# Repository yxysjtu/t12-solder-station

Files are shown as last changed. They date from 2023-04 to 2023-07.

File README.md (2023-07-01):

# t12-solder-station

bare-bone version
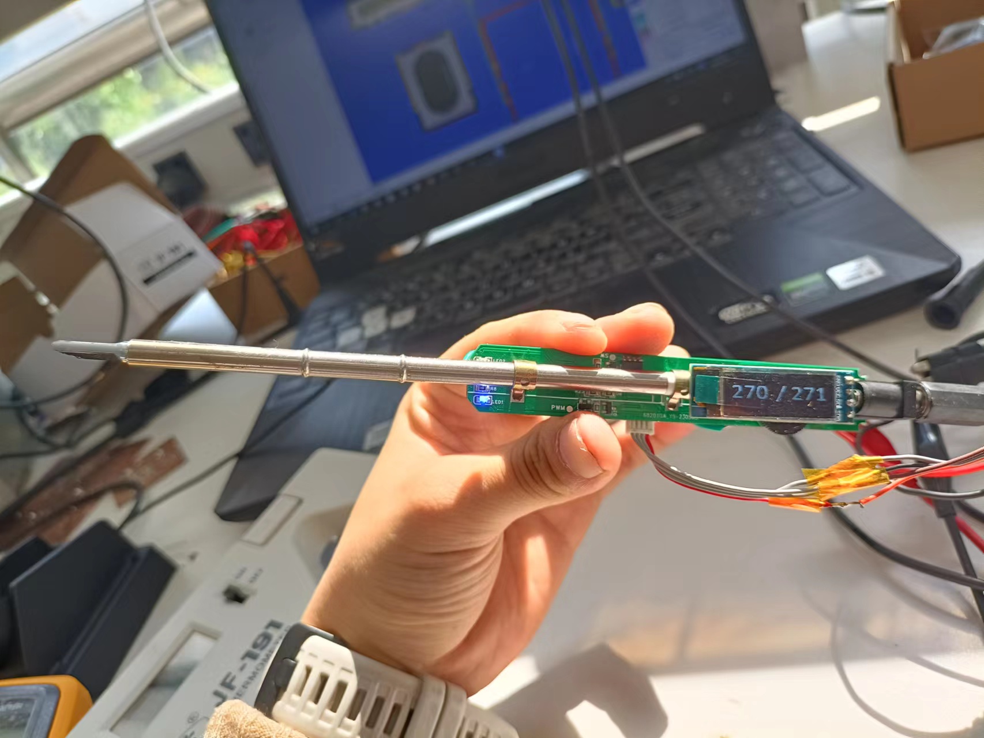
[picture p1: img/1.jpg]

with 3D-printed nylon shell
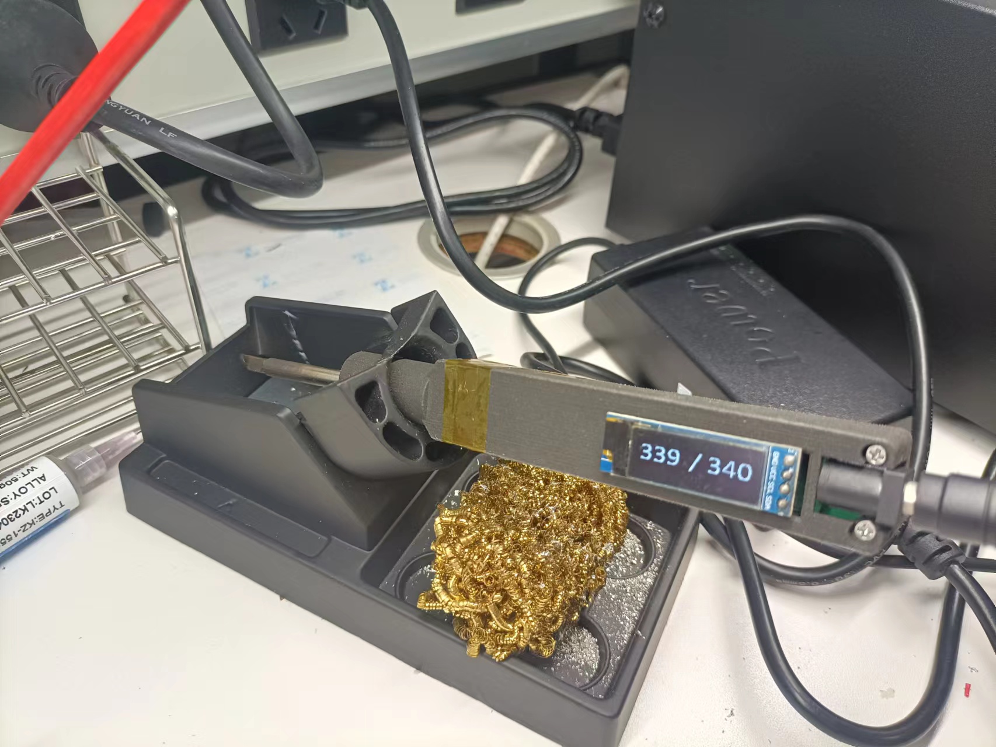
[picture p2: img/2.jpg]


## Feature
* regulate the temperature on the tip of soldering iron according to the set temperature (200 - 400 degree)
* using a 0.92 inch OLED to display current temperature and set temperature
* set the temperature using a rotary potentiometer
* auto sleep and wake function according to sensed vibration

## Working principle
1. using PWM wave to control power output to the iron
2. T12 iron tip is made of a type of thermocouple which can be seen as a 8 ohm resistor in series with a temperature-controlled-voltage-source that output voltage in proportion to temperature(in mV), so I use OPA376 opamp to amplify the voltage between two terminals of the iron(the voltage should be measured between the off stage, because when the iron is on, the voltage across it is 24V(so I use a 3.3V zener diode to clamp the voltage feeding into the input port of the opamp in case of destroying it))
3. the amplified voltage then goes to ADC of the MCU, forming a negative feedback
4. using PID controller to control PWM duty cycle, aiming to regulate temperature fast and accurately

## Schematic
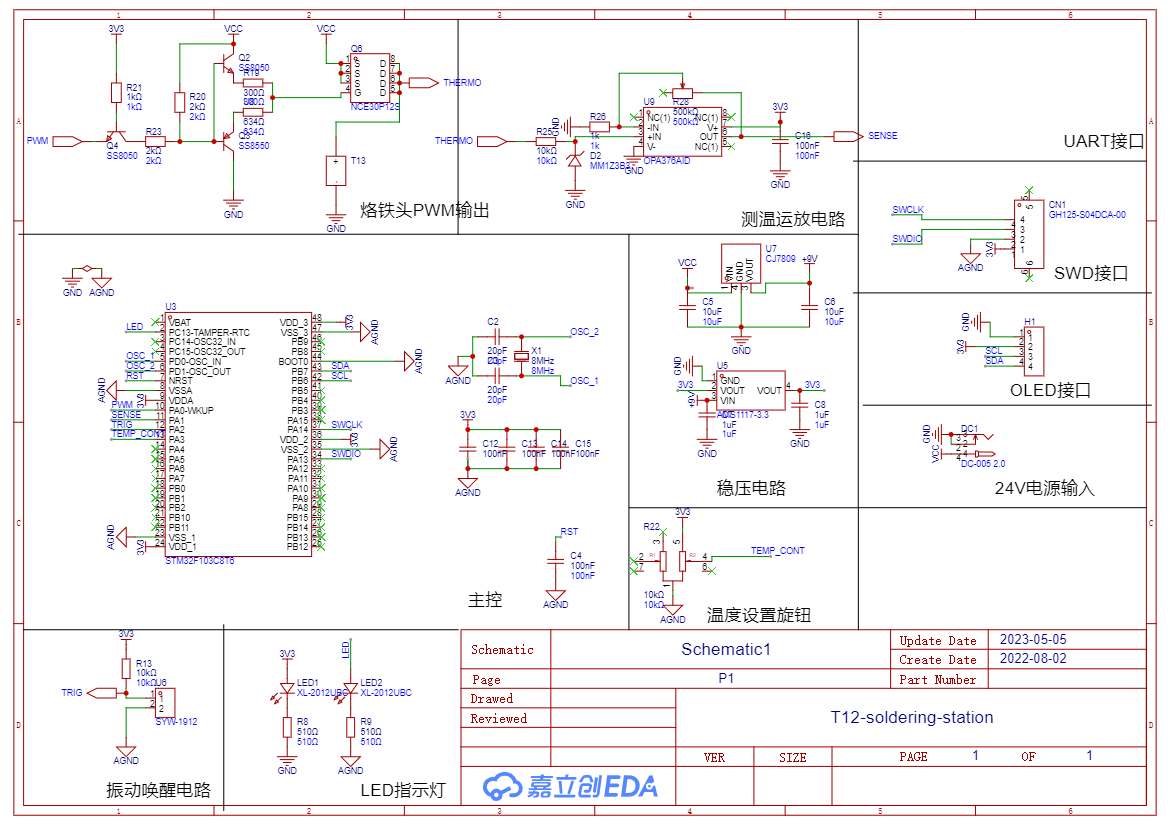
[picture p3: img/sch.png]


## PCB
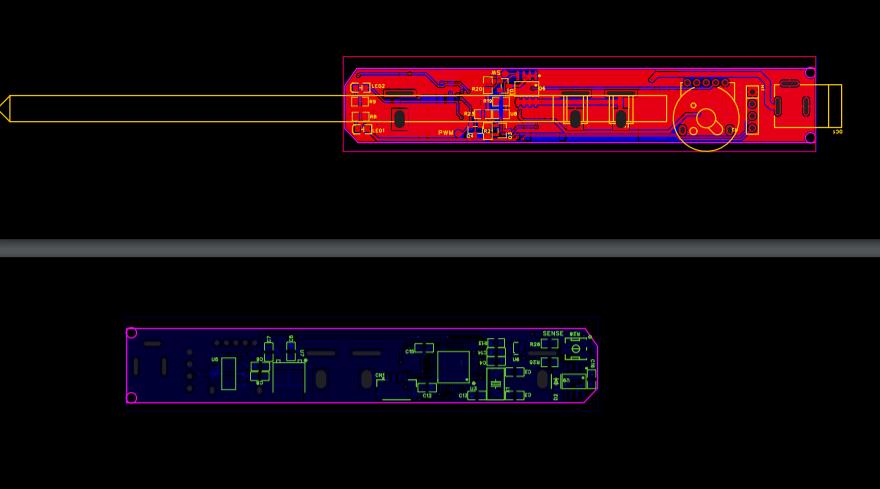
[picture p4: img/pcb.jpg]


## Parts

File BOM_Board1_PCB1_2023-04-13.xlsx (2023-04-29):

No. | Quantity | Comment | Designator | Footprint | Value | Manufacturer Part | Manufacturer | Supplier Part | Supplier
1 | 5 | 100nF | C1,C12,C13,C14,C15 | C0805 | 100nF
2 | 2 | 20pF | C2,C3 | C0805 | 20pF | 0805CG200J500NT | FH(风华) | C94472 | LCSC
3 | 2 | 100nF | C4,C11 | C0805 | 100nF | NL0805B104M500CPBN | HUI JU(汇聚) | C720961 | LCSC
4 | 2 | 10uF | C5,C6 | C0805 | 10uF | GRM21BR61H106KE43L | muRata(村田) | C440198 | LCSC
5 | 2 | 1uF | C7,C8 | C0805 | 1uF | CL21B105KBFNNNE | SAMSUNG(三星) | C28323 | LCSC
6 | 1 | GH125-S04DCA-00 | CN1 | CONN-SMD_4P-P1.27_GH125-S04DCA-00 |  | GH125-S04DCA-00 | JS(钜硕电子) | C2886767 | LCSC
7 | 1 | 70ADJ-2-ML1 | CN3 | CONN-SMD_70ADJ-2-ML1 |  | 70ADJ-2-ML1 | BOURNS | C194556 | LCSC
8 | 1 | MM1Z3B3 | D1 | SOD-123_L2.8-W1.8-LS3.7-FD |  | MM1Z3B3 | ST(先科) | C108453 | LCSC
9 | 1 | DC-005 2.0 | DC1 | DC-IN-TH_DC-5520-1 |  | DC-005 2.0 | BOOMELE(博穆精密) | C16214 | LCSC
10 | 1 |  | H1 | HDR-TH_4P-P2.54-V-M |  |  |  | C492403
11 | 2 | XL-2012UBC | HEAT,POWER | LED0805-RD |  | XL-2012UBC | XINGLIGHT(成兴光) | C965817 | LCSC
12 | 2 | SS8050 | Q2,Q4 | SOT-23-3_L2.9-W1.3-P1.90-LS2.4-BR |  | SS8050 | CJ（江苏长电/长晶） | C2150 | LCSC
13 | 1 | SS8550 | Q3 | SOT-23-3_L2.9-W1.6-P1.90-LS2.8-BR |  | SS8550 | CJ（江苏长电/长晶） | C105430 | LCSC
14 | 1 | AP4410 | Q5 | SOP-8_L4.9-W3.8-P1.27-LS6.0-BL |  | AP4410 | ALLPOWER(铨力) | C2837277 | LCSC
15 | 1 | 5kΩ | R2 | RES-ADJ-SMD_3P-L4.5-W4.5-P2.35-BR | 5kΩ | 3314G-1-502E | BOURNS | C719180 | LCSC
16 | 3 | 10kΩ | R3,R7,R13 | R0805 | 10kΩ | 0805W8F1002T5E | UNI-ROYAL(厚声) | C17414 | LCSC
17 | 1 | 1MΩ | R6 | R0805 | 1MΩ | 0805W8F1004T5E | UNI-ROYAL(厚声) | C17514 | LCSC
18 | 2 | 510Ω | R8,R9 | R0805 | 510Ω | 0805W8F5100T5E | UNI-ROYAL(厚声) | C17734 | LCSC
19 | 2 | 120Ω | R10,R11 | R0805 | 120Ω | 0805W8F1200T5E | UNI-ROYAL(厚声) | C17437 | LCSC
20 | 3 | 1kΩ | R14,R15,R21 | R0805 | 1kΩ | ERJPB6B1001V | PANASONIC(松下) | C413712 | LCSC
21 | 1 | 100Ω | R16 | R0805 | 100Ω | ERJP06J101V | PANASONIC(松下) | C417003 | LCSC
22 | 1 | 300Ω | R19 | R0805 | 300Ω | RK73B2ATTD301J | KOA | C316763 | LCSC
23 | 1 | 2kΩ | R20 | R0805 | 2kΩ | ERJPB6B2001V | PANASONIC(松下) | C413705 | LCSC
24 | 1 | 10kΩ | R22 | RES-TH_RK10J12E002L | 10kΩ | RK10J12E002L | ALPSALPINE(阿尔卑斯阿尔派) | C231765 | LCSC
25 | 1 | INA826AIDR | U2 | SOIC-8_L4.9-W3.9-P1.27-LS6.0-BL |  | INA826AIDR | TI(德州仪器) | C38433 | LCSC
26 | 1 | STM32F103C8T6 | U3 | LQFP-48_L7.0-W7.0-P0.50-LS9.0-BL |  | STM32F103C8T6 | ST(意法半导体) | C8734 | LCSC
27 | 1 | AMS1117-3.3 | U5 | SOT-223-3_L6.5-W3.4-P2.30-LS7.0-BR |  | AMS1117-3.3 | AMS | C6186 | LCSC
28 | 1 | SYW-1912 | U6 | SENSOR-SMD_SYW-1912 |  | SYW-1912 | saiya(赛亚) | C3040975 | LCSC
29 | 1 | CJ7809 | U7 | TO-252-2_L6.5-W6.1-P4.58-LS10.0-TL |  | CJ7809 | CJ（江苏长电/长晶） | C177737 | LCSC
30 | 1 | 634Ω | U8 | R0805 | 634Ω | HPCR0805F634RK9 | RESI(开步睿思） | F | LCSC
31 | 1 | 8MHz | X1 | CRYSTAL-SMD_L5.0-W3.2 | 8MHz | X50328MSB2GI | YXC(扬兴晶振) | C115962 | LCSC

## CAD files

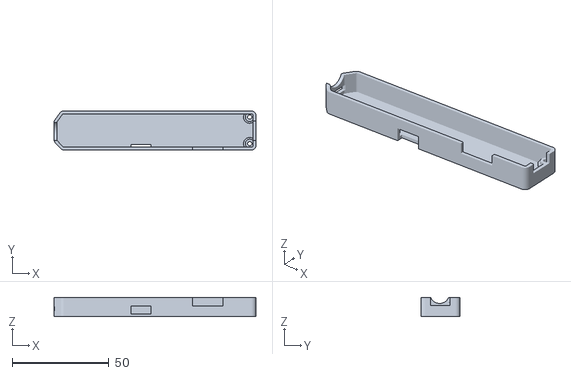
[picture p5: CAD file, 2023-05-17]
3DShell_PCB3/3DShell_3DShell_PCB1_B.stl
104.2 x 20.1 x 10.0

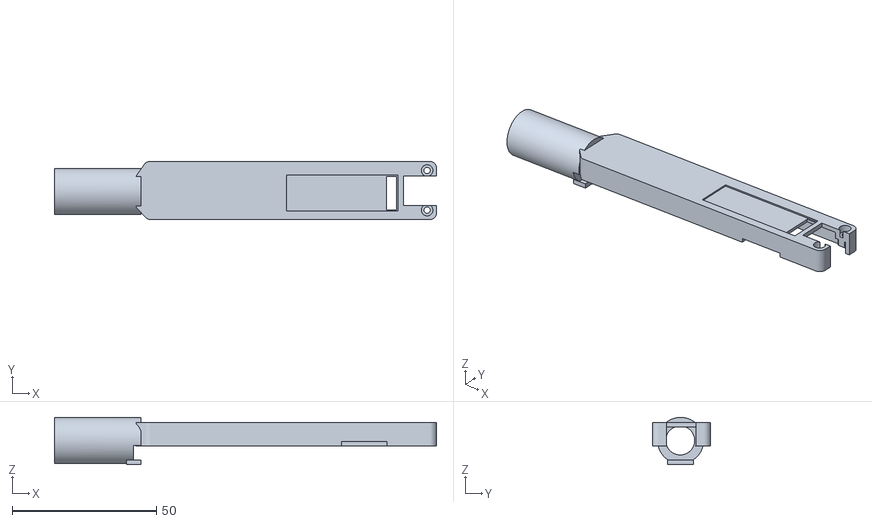
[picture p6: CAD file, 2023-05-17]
3DShell_PCB3/3DShell_3DShell_PCB1_T.stl
132.2 x 20.1 x 16.4

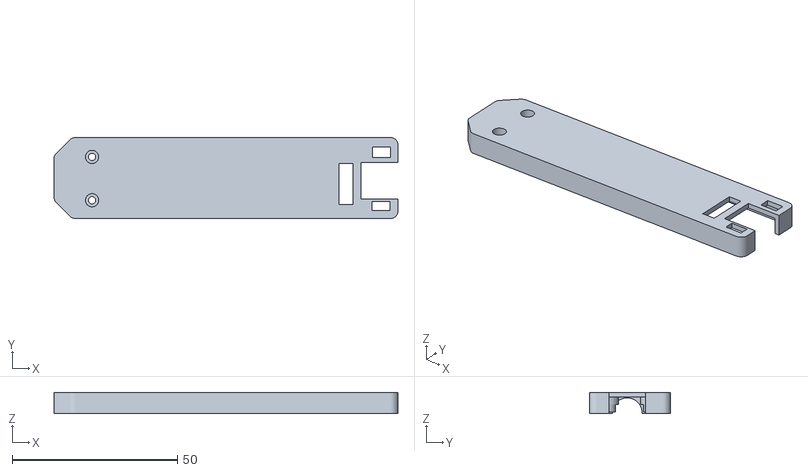
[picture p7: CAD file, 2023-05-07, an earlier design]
3DShell_PCB1/3DShell_3DShell_PCB1_T.stl
104.1 x 24.5 x 6.50

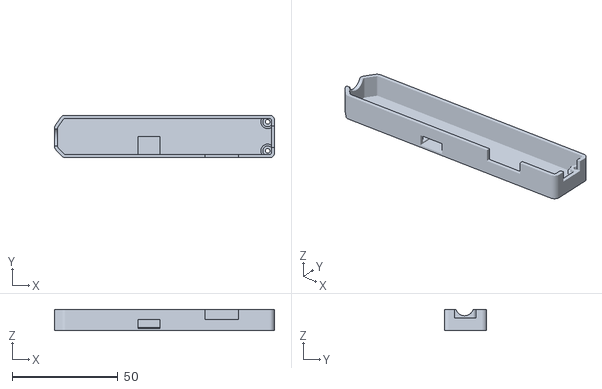
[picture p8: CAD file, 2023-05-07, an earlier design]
3DShell_PCB2/3DShell_3DShell_PCB1_B.stl
104.2 x 20.1 x 10.0

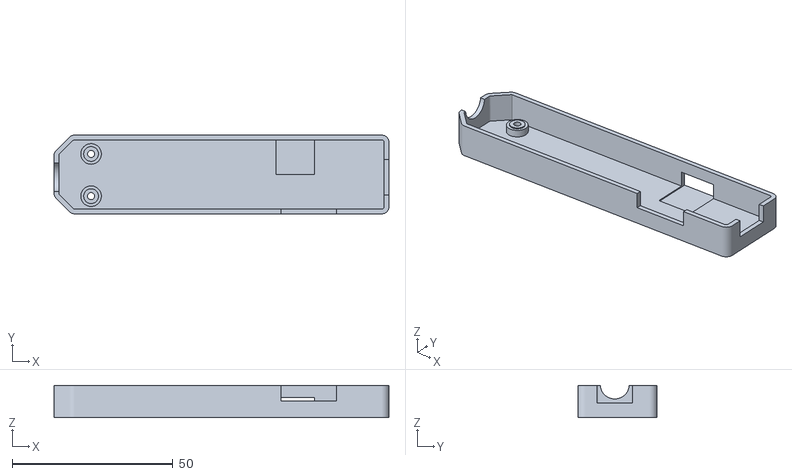
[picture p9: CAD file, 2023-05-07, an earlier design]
3DShell_PCB1/3DShell_3DShell_PCB1_B.stl
104.1 x 24.5 x 10.0

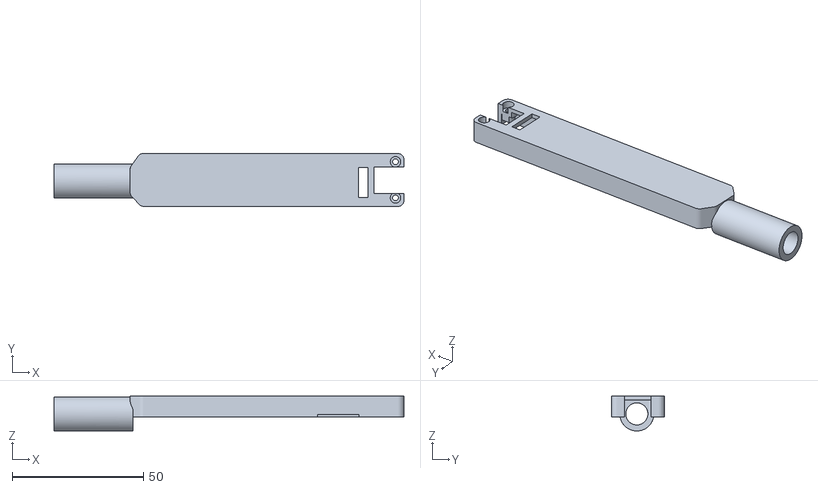
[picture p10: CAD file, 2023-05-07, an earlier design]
3DShell_PCB2/3DShell_3DShell_PCB1_T.stl
133.1 x 20.1 x 13.3

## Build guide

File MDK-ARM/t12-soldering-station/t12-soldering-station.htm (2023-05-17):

# Static Call Graph for image t12-soldering-station\t12-soldering-station.axf

#<CALLGRAPH># ARM Linker, 5060750: Last Updated: Thu May 11 15:21:41 2023

### Maximum Stack Usage = 216 bytes + Unknown(Functions without stacksize, Cycles, Untraceable Function Pointers)

### Call chain for Maximum Stack Depth:

__rt_entry_main ⇒ main ⇒ oled_show ⇒ OLED_ShowCN ⇒ OLED_SetPos ⇒ writeCmd ⇒ HAL_I2C_Mem_Write ⇒ I2C_RequestMemoryWrite ⇒ I2C_WaitOnMasterAddressFlagUntilTimeout

### Functions with no stack information

- __user_initial_stackheap

### Mutually Recursive functions

- ADC1_2_IRQHandler ⇒ ADC1_2_IRQHandler
- BusFault_Handler ⇒ BusFault_Handler
- HardFault_Handler ⇒ HardFault_Handler
- MemManage_Handler ⇒ MemManage_Handler
- NMI_Handler ⇒ NMI_Handler
- UsageFault_Handler ⇒ UsageFault_Handler

### Function Pointers

- ADC1_2_IRQHandler from startup_stm32f103xb.o(.text) referenced from startup_stm32f103xb.o(RESET)
- BusFault_Handler from stm32f1xx_it.o(i.BusFault_Handler) referenced from startup_stm32f103xb.o(RESET)
- CAN1_RX1_IRQHandler from startup_stm32f103xb.o(.text) referenced from startup_stm32f103xb.o(RESET)
- CAN1_SCE_IRQHandler from startup_stm32f103xb.o(.text) referenced from startup_stm32f103xb.o(RESET)
- DMA1_Channel1_IRQHandler from startup_stm32f103xb.o(.text) referenced from startup_stm32f103xb.o(RESET)
- DMA1_Channel2_IRQHandler from startup_stm32f103xb.o(.text) referenced from startup_stm32f103xb.o(RESET)
- DMA1_Channel3_IRQHandler from startup_stm32f103xb.o(.text) referenced from startup_stm32f103xb.o(RESET)
- DMA1_Channel4_IRQHandler from startup_stm32f103xb.o(.text) referenced from startup_stm32f103xb.o(RESET)
- DMA1_Channel5_IRQHandler from startup_stm32f103xb.o(.text) referenced from startup_stm32f103xb.o(RESET)
- DMA1_Channel6_IRQHandler from startup_stm32f103xb.o(.text) referenced from startup_stm32f103xb.o(RESET)
- DMA1_Channel7_IRQHandler from startup_stm32f103xb.o(.text) referenced from startup_stm32f103xb.o(RESET)
- DebugMon_Handler from stm32f1xx_it.o(i.DebugMon_Handler) referenced from startup_stm32f103xb.o(RESET)
- EXTI0_IRQHandler from startup_stm32f103xb.o(.text) referenced from startup_stm32f103xb.o(RESET)
- EXTI15_10_IRQHandler from startup_stm32f103xb.o(.text) referenced from startup_stm32f103xb.o(RESET)
- EXTI1_IRQHandler from startup_stm32f103xb.o(.text) referenced from startup_stm32f103xb.o(RESET)
- EXTI2_IRQHandler from startup_stm32f103xb.o(.text) referenced from startup_stm32f103xb.o(RESET)
- EXTI3_IRQHandler from startup_stm32f103xb.o(.text) referenced from startup_stm32f103xb.o(RESET)
- EXTI4_IRQHandler from startup_stm32f103xb.o(.text) referenced from startup_stm32f103xb.o(RESET)
- EXTI9_5_IRQHandler from startup_stm32f103xb.o(.text) referenced from startup_stm32f103xb.o(RESET)
- FLASH_IRQHandler from startup_stm32f103xb.o(.text) referenced from startup_stm32f103xb.o(RESET)
- HardFault_Handler from stm32f1xx_it.o(i.HardFault_Handler) referenced from startup_stm32f103xb.o(RESET)
- I2C1_ER_IRQHandler from startup_stm32f103xb.o(.text) referenced from startup_stm32f103xb.o(RESET)
- I2C1_EV_IRQHandler from startup_stm32f103xb.o(.text) referenced from startup_stm32f103xb.o(RESET)
- I2C2_ER_IRQHandler from startup_stm32f103xb.o(.text) referenced from startup_stm32f103xb.o(RESET)
- I2C2_EV_IRQHandler from startup_stm32f103xb.o(.text) referenced from startup_stm32f103xb.o(RESET)
- MemManage_Handler from stm32f1xx_it.o(i.MemManage_Handler) referenced from startup_stm32f103xb.o(RESET)
- NMI_Handler from stm32f1xx_it.o(i.NMI_Handler) referenced from startup_stm32f103xb.o(RESET)
- PVD_IRQHandler from startup_stm32f103xb.o(.text) referenced from startup_stm32f103xb.o(RESET)
- PendSV_Handler from stm32f1xx_it.o(i.PendSV_Handler) referenced from startup_stm32f103xb.o(RESET)
- RCC_IRQHandler from startup_stm32f103xb.o(.text) referenced from startup_stm32f103xb.o(RESET)
- RTC_Alarm_IRQHandler from startup_stm32f103xb.o(.text) referenced from startup_stm32f103xb.o(RESET)
- RTC_IRQHandler from startup_stm32f103xb.o(.text) referenced from startup_stm32f103xb.o(RESET)
- Reset_Handler from startup_stm32f103xb.o(.text) referenced from startup_stm32f103xb.o(RESET)
- SPI1_IRQHandler from startup_stm32f103xb.o(.text) referenced from startup_stm32f103xb.o(RESET)
- SPI2_IRQHandler from startup_stm32f103xb.o(.text) referenced from startup_stm32f103xb.o(RESET)
- SVC_Handler from stm32f1xx_it.o(i.SVC_Handler) referenced from startup_stm32f103xb.o(RESET)
- SysTick_Handler from stm32f1xx_it.o(i.SysTick_Handler) referenced from startup_stm32f103xb.o(RESET)
- SystemInit from system_stm32f1xx.o(i.SystemInit) referenced from startup_stm32f103xb.o(.text)
- TAMPER_IRQHandler from startup_stm32f103xb.o(.text) referenced from startup_stm32f103xb.o(RESET)
- TIM1_BRK_IRQHandler from startup_stm32f103xb.o(.text) referenced from startup_stm32f103xb.o(RESET)
- TIM1_CC_IRQHandler from startup_stm32f103xb.o(.text) referenced from startup_stm32f103xb.o(RESET)
- TIM1_TRG_COM_IRQHandler from startup_stm32f103xb.o(.text) referenced from startup_stm32f103xb.o(RESET)
- TIM1_UP_IRQHandler from startup_stm32f103xb.o(.text) referenced from startup_stm32f103xb.o(RESET)
- TIM2_IRQHandler from stm32f1xx_it.o(i.TIM2_IRQHandler) referenced from startup_stm32f103xb.o(RESET)
- TIM3_IRQHandler from startup_stm32f103xb.o(.text) referenced from startup_stm32f103xb.o(RESET)
- TIM4_IRQHandler from startup_stm32f103xb.o(.text) referenced from startup_stm32f103xb.o(RESET)
- USART1_IRQHandler from startup_stm32f103xb.o(.text) referenced from startup_stm32f103xb.o(RESET)
- USART2_IRQHandler from startup_stm32f103xb.o(.text) referenced from startup_stm32f103xb.o(RESET)
- USART3_IRQHandler from startup_stm32f103xb.o(.text) referenced from startup_stm32f103xb.o(RESET)
- USBWakeUp_IRQHandler from startup_stm32f103xb.o(.text) referenced from startup_stm32f103xb.o(RESET)
- USB_HP_CAN1_TX_IRQHandler from startup_stm32f103xb.o(.text) referenced from startup_stm32f103xb.o(RESET)
- USB_LP_CAN1_RX0_IRQHandler from startup_stm32f103xb.o(.text) referenced from startup_stm32f103xb.o(RESET)
- UsageFault_Handler from stm32f1xx_it.o(i.UsageFault_Handler) referenced from startup_stm32f103xb.o(RESET)
- WWDG_IRQHandler from startup_stm32f103xb.o(.text) referenced from startup_stm32f103xb.o(RESET)
- __main from __main.o(!!!main) referenced from startup_stm32f103xb.o(.text)

### Global Symbols

__main (Thumb, 8 bytes, Stack size 0 bytes, __main.o(!!!main))

[Calls]

- >> __rt_entry
- >> __scatterload

__scatterload (Thumb, 0 bytes, Stack size unknown bytes, __scatter.o(!!!scatter))

[Called By]

- >> __main

__scatterload_rt2 (Thumb, 44 bytes, Stack size unknown bytes, __scatter.o(!!!scatter), UNUSED)

[Calls]

- >> __rt_entry

__scatterload_rt2_thumb_only (Thumb, 0 bytes, Stack size unknown bytes, __scatter.o(!!!scatter), UNUSED)

__scatterload_null (Thumb, 0 bytes, Stack size unknown bytes, __scatter.o(!!!scatter), UNUSED)

__decompress (Thumb, 90 bytes, Stack size unknown bytes, __dczerorl2.o(!!dczerorl2), UNUSED)

__decompress1 (Thumb, 0 bytes, Stack size unknown bytes, __dczerorl2.o(!!dczerorl2), UNUSED)

__scatterload_zeroinit (Thumb, 28 bytes, Stack size unknown bytes, __scatter_zi.o(!!handler_zi), UNUSED)

__rt_lib_init (Thumb, 0 bytes, Stack size unknown bytes, libinit.o(.ARM.Collect$$libinit$$00000000))

[Called By]

- >> __rt_entry_li

__rt_lib_init_alloca_1 (Thumb, 0 bytes, Stack size unknown bytes, libinit2.o(.ARM.Collect$$libinit$$0000002E))

__rt_lib_init_argv_1 (Thumb, 0 bytes, Stack size unknown bytes, libinit2.o(.ARM.Collect$$libinit$$0000002C))

__rt_lib_init_atexit_1 (Thumb, 0 bytes, Stack size unknown bytes, libinit2.o(.ARM.Collect$$libinit$$0000001B))

__rt_lib_init_clock_1 (Thumb, 0 bytes, Stack size unknown bytes, libinit2.o(.ARM.Collect$$libinit$$00000021))

__rt_lib_init_cpp_1 (Thumb, 0 bytes, Stack size unknown bytes, libinit2.o(.ARM.Collect$$libinit$$00000032))

__rt_lib_init_exceptions_1 (Thumb, 0 bytes, Stack size unknown bytes, libinit2.o(.ARM.Collect$$libinit$$00000030))

__rt_lib_init_fp_1 (Thumb, 0 bytes, Stack size unknown bytes, libinit2.o(.ARM.Collect$$libinit$$00000002))

__rt_lib_init_fp_trap_1 (Thumb, 0 bytes, Stack size unknown bytes, libinit2.o(.ARM.Collect$$libinit$$0000001F))

__rt_lib_init_getenv_1 (Thumb, 0 bytes, Stack size unknown bytes, libinit2.o(.ARM.Collect$$libinit$$00000023))

__rt_lib_init_heap_1 (Thumb, 0 bytes, Stack size unknown bytes, libinit2.o(.ARM.Collect$$libinit$$0000000A))

__rt_lib_init_lc_collate_1 (Thumb, 0 bytes, Stack size unknown bytes, libinit2.o(.ARM.Collect$$libinit$$00000011))

__rt_lib_init_lc_ctype_1 (Thumb, 0 bytes, Stack size unknown bytes, libinit2.o(.ARM.Collect$$libinit$$00000013))

__rt_lib_init_lc_monetary_1 (Thumb, 0 bytes, Stack size unknown bytes, libinit2.o(.ARM.Collect$$libinit$$00000015))

__rt_lib_init_lc_numeric_1 (Thumb, 0 bytes, Stack size unknown bytes, libinit2.o(.ARM.Collect$$libinit$$00000017))

__rt_lib_init_lc_time_1 (Thumb, 0 bytes, Stack size unknown bytes, libinit2.o(.ARM.Collect$$libinit$$00000019))

__rt_lib_init_preinit_1 (Thumb, 0 bytes, Stack size unknown bytes, libinit2.o(.ARM.Collect$$libinit$$00000004))

__rt_lib_init_rand_1 (Thumb, 0 bytes, Stack size unknown bytes, libinit2.o(.ARM.Collect$$libinit$$0000000E))

__rt_lib_init_return (Thumb, 0 bytes, Stack size unknown bytes, libinit2.o(.ARM.Collect$$libinit$$00000033))

__rt_lib_init_signal_1 (Thumb, 0 bytes, Stack size unknown bytes, libinit2.o(.ARM.Collect$$libinit$$0000001D))

__rt_lib_init_stdio_1 (Thumb, 0 bytes, Stack size unknown bytes, libinit2.o(.ARM.Collect$$libinit$$00000025))

__rt_lib_init_user_alloc_1 (Thumb, 0 bytes, Stack size unknown bytes, libinit2.o(.ARM.Collect$$libinit$$0000000C))

__rt_lib_shutdown (Thumb, 0 bytes, Stack size unknown bytes, libshutdown.o(.ARM.Collect$$libshutdown$$00000000))

[Called By]

- >> __rt_exit_ls

__rt_lib_shutdown_cpp_1 (Thumb, 0 bytes, Stack size unknown bytes, libshutdown2.o(.ARM.Collect$$libshutdown$$00000002))

__rt_lib_shutdown_fp_trap_1 (Thumb, 0 bytes, Stack size unknown bytes, libshutdown2.o(.ARM.Collect$$libshutdown$$00000007))

__rt_lib_shutdown_heap_1 (Thumb, 0 bytes, Stack size unknown bytes, libshutdown2.o(.ARM.Collect$$libshutdown$$0000000F))

__rt_lib_shutdown_return (Thumb, 0 bytes, Stack size unknown bytes, libshutdown2.o(.ARM.Collect$$libshutdown$$00000010))

__rt_lib_shutdown_signal_1 (Thumb, 0 bytes, Stack size unknown bytes, libshutdown2.o(.ARM.Collect$$libshutdown$$0000000A))

__rt_lib_shutdown_stdio_1 (Thumb, 0 bytes, Stack size unknown bytes, libshutdown2.o(.ARM.Collect$$libshutdown$$00000004))

__rt_lib_shutdown_user_alloc_1 (Thumb, 0 bytes, Stack size unknown bytes, libshutdown2.o(.ARM.Collect$$libshutdown$$0000000C))

__rt_entry (Thumb, 0 bytes, Stack size unknown bytes, __rtentry.o(.ARM.Collect$$rtentry$$00000000))

[Called By]

- >> __main
- >> __scatterload_rt2

__rt_entry_presh_1 (Thumb, 0 bytes, Stack size unknown bytes, __rtentry2.o(.ARM.Collect$$rtentry$$00000002))

__rt_entry_sh (Thumb, 0 bytes, Stack size unknown bytes, __rtentry4.o(.ARM.Collect$$rtentry$$00000004))

[Stack]

- Max Depth = 8 + Unknown Stack Size
- Call Chain = __rt_entry_sh ⇒ __user_setup_stackheap

[Calls]

- >> __user_setup_stackheap

__rt_entry_li (Thumb, 0 bytes, Stack size unknown bytes, __rtentry2.o(.ARM.Collect$$rtentry$$0000000A))

[Calls]

- >> __rt_lib_init

__rt_entry_postsh_1 (Thumb, 0 bytes, Stack size unknown bytes, __rtentry2.o(.ARM.Collect$$rtentry$$00000009))

__rt_entry_main (Thumb, 0 bytes, Stack size unknown bytes, __rtentry2.o(.ARM.Collect$$rtentry$$0000000D))

[Stack]

- Max Depth = 216 + Unknown Stack Size
- Call Chain = __rt_entry_main ⇒ main ⇒ oled_show ⇒ OLED_ShowCN ⇒ OLED_SetPos ⇒ writeCmd ⇒ HAL_I2C_Mem_Write ⇒ I2C_RequestMemoryWrite ⇒ I2C_WaitOnMasterAddressFlagUntilTimeout

[Calls]

- >> main
- >> exit

__rt_entry_postli_1 (Thumb, 0 bytes, Stack size unknown bytes, __rtentry2.o(.ARM.Collect$$rtentry$$0000000C))

__rt_exit (Thumb, 0 bytes, Stack size unknown bytes, rtexit.o(.ARM.Collect$$rtexit$$00000000))

[Called By]

- >> exit

__rt_exit_ls (Thumb, 0 bytes, Stack size unknown bytes, rtexit2.o(.ARM.Collect$$rtexit$$00000003))

[Calls]

- >> __rt_lib_shutdown

__rt_exit_prels_1 (Thumb, 0 bytes, Stack size unknown bytes, rtexit2.o(.ARM.Collect$$rtexit$$00000002))

__rt_exit_exit (Thumb, 0 bytes, Stack size unknown bytes, rtexit2.o(.ARM.Collect$$rtexit$$00000004))

[Calls]

- >> _sys_exit

Reset_Handler (Thumb, 8 bytes, Stack size 0 bytes, startup_stm32f103xb.o(.text))
[Address Reference Count : 1]

- startup_stm32f103xb.o(RESET)

ADC1_2_IRQHandler (Thumb, 0 bytes, Stack size 0 bytes, startup_stm32f103xb.o(.text))

[Calls]

- >> ADC1_2_IRQHandler

[Called By]

- >> ADC1_2_IRQHandler

[Address Reference Count : 1]

- startup_stm32f103xb.o(RESET)

CAN1_RX1_IRQHandler (Thumb, 0 bytes, Stack size 0 bytes, startup_stm32f103xb.o(.text))
[Address Reference Count : 1]

- startup_stm32f103xb.o(RESET)

CAN1_SCE_IRQHandler (Thumb, 0 bytes, Stack size 0 bytes, startup_stm32f103xb.o(.text))
[Address Reference Count : 1]

- startup_stm32f103xb.o(RESET)

DMA1_Channel1_IRQHandler (Thumb, 0 bytes, Stack size 0 bytes, startup_stm32f103xb.o(.text))
[Address Reference Count : 1]

- startup_stm32f103xb.o(RESET)

DMA1_Channel2_IRQHandler (Thumb, 0 bytes, Stack size 0 bytes, startup_stm32f103xb.o(.text))
[Address Reference Count : 1]

- startup_stm32f103xb.o(RESET)

DMA1_Channel3_IRQHandler (Thumb, 0 bytes, Stack size 0 bytes, startup_stm32f103xb.o(.text))
[Address Reference Count : 1]

- startup_stm32f103xb.o(RESET)

DMA1_Channel4_IRQHandler (Thumb, 0 bytes, Stack size 0 bytes, startup_stm32f103xb.o(.text))
[Address Reference Count : 1]

- startup_stm32f103xb.o(RESET)

DMA1_Channel5_IRQHandler (Thumb, 0 bytes, Stack size 0 bytes, startup_stm32f103xb.o(.text))
[Address Reference Count : 1]

- startup_stm32f103xb.o(RESET)

DMA1_Channel6_IRQHandler (Thumb, 0 bytes, Stack size 0 bytes, startup_stm32f103xb.o(.text))
[Address Reference Count : 1]

- startup_stm32f103xb.o(RESET)

DMA1_Channel7_IRQHandler (Thumb, 0 bytes, Stack size 0 bytes, startup_stm32f103xb.o(.text))
[Address Reference Count : 1]

- startup_stm32f103xb.o(RESET)

EXTI0_IRQHandler (Thumb, 0 bytes, Stack size 0 bytes, startup_stm32f103xb.o(.text))
[Address Reference Count : 1]

- startup_stm32f103xb.o(RESET)

EXTI15_10_IRQHandler (Thumb, 0 bytes, Stack size 0 bytes, startup_stm32f103xb.o(.text))
[Address Reference Count : 1]

- startup_stm32f103xb.o(RESET)

EXTI1_IRQHandler (Thumb, 0 bytes, Stack size 0 bytes, startup_stm32f103xb.o(.text))
[Address Reference Count : 1]

- startup_stm32f103xb.o(RESET)

EXTI2_IRQHandler (Thumb, 0 bytes, Stack size 0 bytes, startup_stm32f103xb.o(.text))
[Address Reference Count : 1]

- startup_stm32f103xb.o(RESET)

EXTI3_IRQHandler (Thumb, 0 bytes, Stack size 0 bytes, startup_stm32f103xb.o(.text))
[Address Reference Count : 1]

- startup_stm32f103xb.o(RESET)

EXTI4_IRQHandler (Thumb, 0 bytes, Stack size 0 bytes, startup_stm32f103xb.o(.text))
[Address Reference Count : 1]

- startup_stm32f103xb.o(RESET)

EXTI9_5_IRQHandler (Thumb, 0 bytes, Stack size 0 bytes, startup_stm32f103xb.o(.text))
[Address Reference Count : 1]

- startup_stm32f103xb.o(RESET)

FLASH_IRQHandler (Thumb, 0 bytes, Stack size 0 bytes, startup_stm32f103xb.o(.text))
[Address Reference Count : 1]

- startup_stm32f103xb.o(RESET)

I2C1_ER_IRQHandler (Thumb, 0 bytes, Stack size 0 bytes, startup_stm32f103xb.o(.text))
[Address Reference Count : 1]

- startup_stm32f103xb.o(RESET)

I2C1_EV_IRQHandler (Thumb, 0 bytes, Stack size 0 bytes, startup_stm32f103xb.o(.text))
[Address Reference Count : 1]

- startup_stm32f103xb.o(RESET)

I2C2_ER_IRQHandler (Thumb, 0 bytes, Stack size 0 bytes, startup_stm32f103xb.o(.text))
[Address Reference Count : 1]

- startup_stm32f103xb.o(RESET)

I2C2_EV_IRQHandler (Thumb, 0 bytes, Stack size 0 bytes, startup_stm32f103xb.o(.text))
[Address Reference Count : 1]

- startup_stm32f103xb.o(RESET)

PVD_IRQHandler (Thumb, 0 bytes, Stack size 0 bytes, startup_stm32f103xb.o(.text))
[Address Reference Count : 1]

- startup_stm32f103xb.o(RESET)

RCC_IRQHandler (Thumb, 0 bytes, Stack size 0 bytes, startup_stm32f103xb.o(.text))
[Address Reference Count : 1]

- startup_stm32f103xb.o(RESET)

RTC_Alarm_IRQHandler (Thumb, 0 bytes, Stack size 0 bytes, startup_stm32f103xb.o(.text))
[Address Reference Count : 1]

- startup_stm32f103xb.o(RESET)

RTC_IRQHandler (Thumb, 0 bytes, Stack size 0 bytes, startup_stm32f103xb.o(.text))
[Address Reference Count : 1]

- startup_stm32f103xb.o(RESET)

SPI1_IRQHandler (Thumb, 0 bytes, Stack size 0 bytes, startup_stm32f103xb.o(.text))
[Address Reference Count : 1]

- startup_stm32f103xb.o(RESET)

SPI2_IRQHandler (Thumb, 0 bytes, Stack size 0 bytes, startup_stm32f103xb.o(.text))
[Address Reference Count : 1]

- startup_stm32f103xb.o(RESET)

TAMPER_IRQHandler (Thumb, 0 bytes, Stack size 0 bytes, startup_stm32f103xb.o(.text))
[Address Reference Count : 1]

- startup_stm32f103xb.o(RESET)

TIM1_BRK_IRQHandler (Thumb, 0 bytes, Stack size 0 bytes, startup_stm32f103xb.o(.text))
[Address Reference Count : 1]

- startup_stm32f103xb.o(RESET)

TIM1_CC_IRQHandler (Thumb, 0 bytes, Stack size 0 bytes, startup_stm32f103xb.o(.text))
[Address Reference Count : 1]

- startup_stm32f103xb.o(RESET)

TIM1_TRG_COM_IRQHandler (Thumb, 0 bytes, Stack size 0 bytes, startup_stm32f103xb.o(.text))
[Address Reference Count : 1]

- startup_stm32f103xb.o(RESET)

TIM1_UP_IRQHandler (Thumb, 0 bytes, Stack size 0 bytes, startup_stm32f103xb.o(.text))
[Address Reference Count : 1]

- startup_stm32f103xb.o(RESET)

TIM3_IRQHandler (Thumb, 0 bytes, Stack size 0 bytes, startup_stm32f103xb.o(.text))
[Address Reference Count : 1]

- startup_stm32f103xb.o(RESET)

TIM4_IRQHandler (Thumb, 0 bytes, Stack size 0 bytes, startup_stm32f103xb.o(.text))
[Address Reference Count : 1]

- startup_stm32f103xb.o(RESET)

USART1_IRQHandler (Thumb, 0 bytes, Stack size 0 bytes, startup_stm32f103xb.o(.text))
[Address Reference Count : 1]

- startup_stm32f103xb.o(RESET)

USART2_IRQHandler (Thumb, 0 bytes, Stack size 0 bytes, startup_stm32f103xb.o(.text))
[Address Reference Count : 1]

- startup_stm32f103xb.o(RESET)

USART3_IRQHandler (Thumb, 0 bytes, Stack size 0 bytes, startup_stm32f103xb.o(.text))
[Address Reference Count : 1]

- startup_stm32f103xb.o(RESET)

USBWakeUp_IRQHandler (Thumb, 0 bytes, Stack size 0 bytes, startup_stm32f103xb.o(.text))
[Address Reference Count : 1]

- startup_stm32f103xb.o(RESET)

USB_HP_CAN1_TX_IRQHandler (Thumb, 0 bytes, Stack size 0 bytes, startup_stm32f103xb.o(.text))
[Address Reference Count : 1]

- startup_stm32f103xb.o(RESET)

USB_LP_CAN1_RX0_IRQHandler (Thumb, 0 bytes, Stack size 0 bytes, startup_stm32f103xb.o(.text))
[Address Reference Count : 1]

- startup_stm32f103xb.o(RESET)

WWDG_IRQHandler (Thumb, 0 bytes, Stack size 0 bytes, startup_stm32f103xb.o(.text))
[Address Reference Count : 1]

- startup_stm32f103xb.o(RESET)

__user_initial_stackheap (Thumb, 0 bytes, Stack size unknown bytes, startup_stm32f103xb.o(.text))

[Called By]

- >> __user_setup_stackheap

__aeabi_memclr4 (Thumb, 0 bytes, Stack size 4 bytes, rt_memclr_w.o(.text))

[Stack]

- Max Depth = 4
- Call Chain = __aeabi_memclr4

[Called By]

- >> MX_TIM2_Init
- >> SystemClock_Config

__aeabi_memclr8 (Thumb, 0 bytes, Stack size 4 bytes, rt_memclr_w.o(.text), UNUSED)

__rt_memclr_w (Thumb, 78 bytes, Stack size 4 bytes, rt_memclr_w.o(.text), UNUSED)

_memset_w (Thumb, 0 bytes, Stack size unknown bytes, rt_memclr_w.o(.text), UNUSED)

__use_two_region_memory (Thumb, 2 bytes, Stack size 0 bytes, heapauxi.o(.text), UNUSED)

__rt_heap_escrow$2region (Thumb, 2 bytes, Stack size 0 bytes, heapauxi.o(.text), UNUSED)

__rt_heap_expand$2region (Thumb, 2 bytes, Stack size 0 bytes, heapauxi.o(.text), UNUSED)

__user_setup_stackheap (Thumb, 74 bytes, Stack size 8 bytes, sys_stackheap_outer.o(.text))

[Stack]

- Max Depth = 8 + Unknown Stack Size
- Call Chain = __user_setup_stackheap

[Calls]

- >> __user_initial_stackheap
- >> __user_perproc_libspace

[Called By]

- >> __rt_entry_sh

exit (Thumb, 18 bytes, Stack size 8 bytes, exit.o(.text))

[Stack]

- Max Depth = 8 + Unknown Stack Size
- Call Chain = exit

[Calls]

- >> __rt_exit

[Called By]

- >> __rt_entry_main

__user_libspace (Thumb, 8 bytes, Stack size 0 bytes, libspace.o(.text), UNUSED)

__user_perproc_libspace (Thumb, 0 bytes, Stack size 0 bytes, libspace.o(.text))

[Called By]

- >> __user_setup_stackheap

__user_perthread_libspace (Thumb, 0 bytes, Stack size 0 bytes, libspace.o(.text), UNUSED)

_sys_exit (Thumb, 8 bytes, Stack size 0 bytes, sys_exit.o(.text))

[Called By]

- >> __rt_exit_exit

__I$use$semihosting (Thumb, 0 bytes, Stack size 0 bytes, use_no_semi.o(.text), UNUSED)

__use_no_semihosting_swi (Thumb, 2 bytes, Stack size 0 bytes, use_no_semi.o(.text), UNUSED)

__semihosting_library_function (Thumb, 0 bytes, Stack size unknown bytes, indicate_semi.o(.text), UNUSED)

ADC_ConversionStop_Disable (Thumb, 86 bytes, Stack size 16 bytes, stm32f1xx_hal_adc.o(i.ADC_ConversionStop_Disable))

[Stack]

- Max Depth = 16
- Call Chain = ADC_ConversionStop_Disable

[Calls]

- >> HAL_GetTick

[Called By]

- >> HAL_ADC_Init
- >> HAL_ADC_Stop

ADC_Enable (Thumb, 114 bytes, Stack size 24 bytes, stm32f1xx_hal_adc.o(i.ADC_Enable))

[Stack]

- Max Depth = 24
- Call Chain = ADC_Enable

[Calls]

- >> HAL_GetTick

[Called By]

- >> HAL_ADC_Start

ADC_Select_CH (Thumb, 30 bytes, Stack size 16 bytes, main.o(i.ADC_Select_CH))

[Stack]

- Max Depth = 40
- Call Chain = ADC_Select_CH ⇒ HAL_ADC_ConfigChannel

[Calls]

- >> HAL_ADC_ConfigChannel

[Called By]

- >> adc_scan

BusFault_Handler (Thumb, 2 bytes, Stack size 0 bytes, stm32f1xx_it.o(i.BusFault_Handler))

[Calls]

- >> BusFault_Handler

[Called By]

- >> BusFault_Handler

[Address Reference Count : 1]

- startup_stm32f103xb.o(RESET)

DebugMon_Handler (Thumb, 2 bytes, Stack size 0 bytes, stm32f1xx_it.o(i.DebugMon_Handler))
[Address Reference Count : 1]

- startup_stm32f103xb.o(RESET)

Error_Handler (Thumb, 4 bytes, Stack size 0 bytes, main.o(i.Error_Handler))

[Called By]

- >> MX_USART1_UART_Init
- >> MX_TIM2_Init
- >> MX_IWDG_Init
- >> MX_I2C1_Init
- >> MX_ADC1_Init

HAL_ADC_ConfigChannel (Thumb, 240 bytes, Stack size 24 bytes, stm32f1xx_hal_adc.o(i.HAL_ADC_ConfigChannel))

[Stack]

- Max Depth = 24
- Call Chain = HAL_ADC_ConfigChannel

[Called By]

- >> MX_ADC1_Init
- >> ADC_Select_CH

HAL_ADC_GetValue (Thumb, 6 bytes, Stack size 0 bytes, stm32f1xx_hal_adc.o(i.HAL_ADC_GetValue))

[Called By]

- >> adc_scan

HAL_ADC_Init (Thumb, 272 bytes, Stack size 24 bytes, stm32f1xx_hal_adc.o(i.HAL_ADC_Init))

[Stack]

- Max Depth = 88
- Call Chain = HAL_ADC_Init ⇒ HAL_ADC_MspInit ⇒ HAL_GPIO_Init

[Calls]

- >> HAL_ADC_MspInit
- >> ADC_ConversionStop_Disable

[Called By]

- >> MX_ADC1_Init

HAL_ADC_MspInit (Thumb, 76 bytes, Stack size 24 bytes, adc.o(i.HAL_ADC_MspInit))

[Stack]

- Max Depth = 64
- Call Chain = HAL_ADC_MspInit ⇒ HAL_GPIO_Init

[Calls]

- >> HAL_GPIO_Init

[Called By]

- >> HAL_ADC_Init

HAL_ADC_PollForConversion (Thumb, 304 bytes, Stack size 32 bytes, stm32f1xx_hal_adc.o(i.HAL_ADC_PollForConversion))

[Stack]

- Max Depth = 64
- Call Chain = HAL_ADC_PollForConversion ⇒ HAL_RCCEx_GetPeriphCLKFreq

[Calls]

- >> HAL_RCCEx_GetPeriphCLKFreq
- >> HAL_GetTick

[Called By]

- >> adc_scan

HAL_ADC_Start (Thumb, 184 bytes, Stack size 16 bytes, stm32f1xx_hal_adc.o(i.HAL_ADC_Start))

[Stack]

- Max Depth = 40
- Call Chain = HAL_ADC_Start ⇒ ADC_Enable

[Calls]

- >> ADC_Enable

[Called By]

- >> adc_scan

HAL_ADC_Stop (Thumb, 52 bytes, Stack size 8 bytes, stm32f1xx_hal_adc.o(i.HAL_ADC_Stop))

[Stack]

- Max Depth = 24
- Call Chain = HAL_ADC_Stop ⇒ ADC_ConversionStop_Disable

[Calls]

- >> ADC_ConversionStop_Disable

[Called By]

- >> adc_scan

HAL_Delay (Thumb, 32 bytes, Stack size 16 bytes, stm32f1xx_hal.o(i.HAL_Delay))

[Stack]

- Max Depth = 16
- Call Chain = HAL_Delay

[Calls]

- >> HAL_GetTick

[Called By]

- >> OLED_Init
- >> main

HAL_GPIO_DeInit (Thumb, 228 bytes, Stack size 28 bytes, stm32f1xx_hal_gpio.o(i.HAL_GPIO_DeInit))

[Stack]

- Max Depth = 28
- Call Chain = HAL_GPIO_DeInit

[Called By]

- >> HAL_I2C_MspDeInit

HAL_GPIO_Init (Thumb, 446 bytes, Stack size 40 bytes, stm32f1xx_hal_gpio.o(i.HAL_GPIO_Init))

[Stack]

- Max Depth = 40
- Call Chain = HAL_GPIO_Init

[Called By]

- >> HAL_UART_MspInit
- >> HAL_TIM_MspPostInit
- >> HAL_ADC_MspInit
- >> MX_GPIO_Init
- >> HAL_I2C_MspInit

HAL_GPIO_TogglePin (Thumb, 16 bytes, Stack size 0 bytes, stm32f1xx_hal_gpio.o(i.HAL_GPIO_TogglePin))

[Called By]

- >> main

HAL_GPIO_WritePin (Thumb, 10 bytes, Stack size 0 bytes, stm32f1xx_hal_gpio.o(i.HAL_GPIO_WritePin))

[Called By]

- >> MX_GPIO_Init

HAL_GetTick (Thumb, 6 bytes, Stack size 0 bytes, stm32f1xx_hal.o(i.HAL_GetTick))

[Called By]

- >> HAL_IWDG_Init
- >> HAL_RCC_OscConfig
- >> HAL_RCC_ClockConfig
- >> HAL_RCCEx_PeriphCLKConfig
- >> HAL_Delay
- >> HAL_ADC_PollForConversion
- >> ADC_Enable
- >> ADC_ConversionStop_Disable
- >> HAL_I2C_Mem_Write
- >> I2C_WaitOnTXEFlagUntilTimeout
- >> I2C_WaitOnMasterAddressFlagUntilTimeout
- >> I2C_WaitOnFlagUntilTimeout
- >> I2C_WaitOnBTFFlagUntilTimeout

HAL_I2C_Init (Thumb, 376 bytes, Stack size 16 bytes, stm32f1xx_hal_i2c.o(i.HAL_I2C_Init))

[Stack]

- Max Depth = 88
- Call Chain = HAL_I2C_Init ⇒ HAL_I2C_MspInit ⇒ HAL_GPIO_Init

[Calls]

- >> HAL_I2C_MspInit
- >> HAL_RCC_GetPCLK1Freq

[Called By]

- >> MX_I2C1_Init

HAL_I2C_Mem_Write (Thumb, 294 bytes, Stack size 64 bytes, stm32f1xx_hal_i2c.o(i.HAL_I2C_Mem_Write))

[Stack]

- Max Depth = 128
- Call Chain = HAL_I2C_Mem_Write ⇒ I2C_RequestMemoryWrite ⇒ I2C_WaitOnMasterAddressFlagUntilTimeout

[Calls]

- >> HAL_GetTick
- >> I2C_WaitOnTXEFlagUntilTimeout
- >> I2C_WaitOnFlagUntilTimeout
- >> I2C_WaitOnBTFFlagUntilTimeout
- >> I2C_RequestMemoryWrite

[Called By]

- >> writeDat
- >> writeCmd

HAL_I2C_MspDeInit (Thumb, 44 bytes, Stack size 8 bytes, i2c.o(i.HAL_I2C_MspDeInit))

[Stack]

- Max Depth = 36
- Call Chain = HAL_I2C_MspDeInit ⇒ HAL_GPIO_DeInit

[Calls]

- >> HAL_GPIO_DeInit

[Called By]

- >> oled_show

HAL_I2C_MspInit (Thumb, 80 bytes, Stack size 32 bytes, i2c.o(i.HAL_I2C_MspInit))

[Stack]

- Max Depth = 72
- Call Chain = HAL_I2C_MspInit ⇒ HAL_GPIO_Init

[Calls]

- >> HAL_GPIO_Init

[Called By]

- >> HAL_I2C_Init
- >> oled_show

HAL_IWDG_Init (Thumb, 90 bytes, Stack size 16 bytes, stm32f1xx_hal_iwdg.o(i.HAL_IWDG_Init))

[Stack]

- Max Depth = 16
- Call Chain = HAL_IWDG_Init

[Calls]

- >> HAL_GetTick

[Called By]

- >> MX_IWDG_Init

HAL_IWDG_Refresh (Thumb, 12 bytes, Stack size 0 bytes, stm32f1xx_hal_iwdg.o(i.HAL_IWDG_Refresh))

[Called By]

- >> main
- >> HAL_TIM_OC_DelayElapsedCallback

HAL_IncTick (Thumb, 12 bytes, Stack size 0 bytes, stm32f1xx_hal.o(i.HAL_IncTick))

[Called By]

- >> SysTick_Handler

HAL_Init (Thumb, 32 bytes, Stack size 8 bytes, stm32f1xx_hal.o(i.HAL_Init))

[Stack]

- Max Depth = 40
- Call Chain = HAL_Init ⇒ HAL_InitTick ⇒ HAL_NVIC_SetPriority

[Calls]

- >> HAL_MspInit
- >> HAL_InitTick
- >> HAL_NVIC_SetPriorityGrouping

[Called By]

- >> main

HAL_InitTick (Thumb, 54 bytes, Stack size 16 bytes, stm32f1xx_hal.o(i.HAL_InitTick))

[Stack]

- Max Depth = 32
- Call Chain = HAL_InitTick ⇒ HAL_NVIC_SetPriority

[Calls]

- >> HAL_NVIC_SetPriority
- >> HAL_SYSTICK_Config

[Called By]

- >> HAL_RCC_ClockConfig
- >> HAL_Init

HAL_MspInit (Thumb, 52 bytes, Stack size 8 bytes, stm32f1xx_hal_msp.o(i.HAL_MspInit))

[Stack]

- Max Depth = 8
- Call Chain = HAL_MspInit

[Called By]

- >> HAL_Init

HAL_NVIC_EnableIRQ (Thumb, 26 bytes, Stack size 0 bytes, stm32f1xx_hal_cortex.o(i.HAL_NVIC_EnableIRQ))

[Called By]

- >> HAL_TIM_Base_MspInit

HAL_NVIC_SetPriority (Thumb, 60 bytes, Stack size 16 bytes, stm32f1xx_hal_cortex.o(i.HAL_NVIC_SetPriority))

[Stack]

- Max Depth = 16
- Call Chain = HAL_NVIC_SetPriority

[Calls]

- >> __NVIC_SetPriority

[Called By]

- >> HAL_TIM_Base_MspInit
- >> HAL_InitTick

HAL_NVIC_SetPriorityGrouping (Thumb, 26 bytes, Stack size 0 bytes, stm32f1xx_hal_cortex.o(i.HAL_NVIC_SetPriorityGrouping))

[Called By]

- >> HAL_Init

HAL_RCCEx_GetPeriphCLKFreq (Thumb, 166 bytes, Stack size 32 bytes, stm32f1xx_hal_rcc_ex.o(i.HAL_RCCEx_GetPeriphCLKFreq))

[Stack]

- Max Depth = 32
- Call Chain = HAL_RCCEx_GetPeriphCLKFreq

[Calls]

- >> HAL_RCC_GetPCLK2Freq

[Called By]

- >> HAL_ADC_PollForConversion

HAL_RCCEx_PeriphCLKConfig (Thumb, 224 bytes, Stack size 32 bytes, stm32f1xx_hal_rcc_ex.o(i.HAL_RCCEx_PeriphCLKConfig))

[Stack]

- Max Depth = 32
- Call Chain = HAL_RCCEx_PeriphCLKConfig

[Calls]

- >> HAL_GetTick

[Called By]

- >> SystemClock_Config

HAL_RCC_ClockConfig (Thumb, 280 bytes, Stack size 32 bytes, stm32f1xx_hal_rcc.o(i.HAL_RCC_ClockConfig))

[Stack]

- Max Depth = 64
- Call Chain = HAL_RCC_ClockConfig ⇒ HAL_InitTick ⇒ HAL_NVIC_SetPriority

[Calls]

- >> HAL_RCC_GetSysClockFreq
- >> HAL_InitTick
- >> HAL_GetTick

[Called By]

- >> SystemClock_Config

HAL_RCC_GetPCLK1Freq (Thumb, 20 bytes, Stack size 0 bytes, stm32f1xx_hal_rcc.o(i.HAL_RCC_GetPCLK1Freq))

[Called By]

- >> HAL_I2C_Init
- >> UART_SetConfig

HAL_RCC_GetPCLK2Freq (Thumb, 20 bytes, Stack size 0 bytes, stm32f1xx_hal_rcc.o(i.HAL_RCC_GetPCLK2Freq))

[Called By]

- >> HAL_RCCEx_GetPeriphCLKFreq
- >> UART_SetConfig

HAL_RCC_GetSysClockFreq (Thumb, 74 bytes, Stack size 20 bytes, stm32f1xx_hal_rcc.o(i.HAL_RCC_GetSysClockFreq))

[Stack]

- Max Depth = 20
- Call Chain = HAL_RCC_GetSysClockFreq

[Called By]

- >> HAL_RCC_ClockConfig

HAL_RCC_OscConfig (Thumb, 778 bytes, Stack size 40 bytes, stm32f1xx_hal_rcc.o(i.HAL_RCC_OscConfig))

[Stack]

- Max Depth = 40
- Call Chain = HAL_RCC_OscConfig

[Calls]

- >> HAL_GetTick

[Called By]

- >> SystemClock_Config

HAL_SYSTICK_Config (Thumb, 40 bytes, Stack size 8 bytes, stm32f1xx_hal_cortex.o(i.HAL_SYSTICK_Config))

[Stack]

- Max Depth = 8
- Call Chain = HAL_SYSTICK_Config

[Calls]

- >> __NVIC_SetPriority

[Called By]

- >> HAL_InitTick

HAL_TIMEx_BreakCallback (Thumb, 2 bytes, Stack size 0 bytes, stm32f1xx_hal_tim_ex.o(i.HAL_TIMEx_BreakCallback))

[Called By]

- >> HAL_TIM_IRQHandler

HAL_TIMEx_CommutCallback (Thumb, 2 bytes, Stack size 0 bytes, stm32f1xx_hal_tim_ex.o(i.HAL_TIMEx_CommutCallback))

[Called By]

- >> HAL_TIM_IRQHandler

HAL_TIMEx_MasterConfigSynchronization (Thumb, 92 bytes, Stack size 16 bytes, stm32f1xx_hal_tim_ex.o(i.HAL_TIMEx_MasterConfigSynchronization))

[Stack]

- Max Depth = 16
- Call Chain = HAL_TIMEx_MasterConfigSynchronization

[Called By]

- >> MX_TIM2_Init

HAL_TIM_Base_Init (Thumb, 90 bytes, Stack size 8 bytes, stm32f1xx_hal_tim.o(i.HAL_TIM_Base_Init))

[Stack]

- Max Depth = 32
- Call Chain = HAL_TIM_Base_Init ⇒ HAL_TIM_Base_MspInit ⇒ HAL_NVIC_SetPriority

[Calls]

- >> HAL_TIM_Base_MspInit
- >> TIM_Base_SetConfig

[Called By]

- >> MX_TIM2_Init

HAL_TIM_Base_MspInit (Thumb, 50 bytes, Stack size 8 bytes, tim.o(i.HAL_TIM_Base_MspInit))

[Stack]

- Max Depth = 24
- Call Chain = HAL_TIM_Base_MspInit ⇒ HAL_NVIC_SetPriority

[Calls]

- >> HAL_NVIC_SetPriority
- >> HAL_NVIC_EnableIRQ

[Called By]

- >> HAL_TIM_Base_Init

HAL_TIM_Base_Start_IT (Thumb, 76 bytes, Stack size 0 bytes, stm32f1xx_hal_tim.o(i.HAL_TIM_Base_Start_IT))

[Called By]

- >> main

HAL_TIM_ConfigClockSource (Thumb, 214 bytes, Stack size 16 bytes, stm32f1xx_hal_tim.o(i.HAL_TIM_ConfigClockSource))

[Stack]

- Max Depth = 24
- Call Chain = HAL_TIM_ConfigClockSource ⇒ TIM_ETR_SetConfig

[Calls]

- >> TIM_ETR_SetConfig
- >> TIM_TI2_ConfigInputStage
- >> TIM_TI1_ConfigInputStage
- >> TIM_ITRx_SetConfig

[Called By]

- >> MX_TIM2_Init

HAL_TIM_IC_CaptureCallback (Thumb, 2 bytes, Stack size 0 bytes, stm32f1xx_hal_tim.o(i.HAL_TIM_IC_CaptureCallback))

[Called By]

- >> HAL_TIM_IRQHandler

HAL_TIM_IRQHandler (Thumb, 358 bytes, Stack size 16 bytes, stm32f1xx_hal_tim.o(i.HAL_TIM_IRQHandler))

[Stack]

- Max Depth = 152
- Call Chain = HAL_TIM_IRQHandler ⇒ HAL_TIM_OC_DelayElapsedCallback ⇒ adc_scan ⇒ HAL_ADC_PollForConversion ⇒ HAL_RCCEx_GetPeriphCLKFreq

[Calls]

- >> HAL_TIM_OC_DelayElapsedCallback
- >> HAL_TIM_TriggerCallback
- >> HAL_TIM_PeriodElapsedCallback
- >> HAL_TIM_PWM_PulseFinishedCallback
- >> HAL_TIM_IC_CaptureCallback
- >> HAL_TIMEx_CommutCallback
- >> HAL_TIMEx_BreakCallback

[Called By]

- >> TIM2_IRQHandler

HAL_TIM_MspPostInit (Thumb, 62 bytes, Stack size 24 bytes, tim.o(i.HAL_TIM_MspPostInit))

[Stack]

- Max Depth = 64
- Call Chain = HAL_TIM_MspPostInit ⇒ HAL_GPIO_Init

[Calls]

- >> HAL_GPIO_Init

[Called By]

- >> MX_TIM2_Init

HAL_TIM_OC_ConfigChannel (Thumb, 76 bytes, Stack size 8 bytes, stm32f1xx_hal_tim.o(i.HAL_TIM_OC_ConfigChannel))

[Stack]

- Max Depth = 20
- Call Chain = HAL_TIM_OC_ConfigChannel ⇒ TIM_OC2_SetConfig

[Calls]

- >> TIM_OC2_SetConfig
- >> TIM_OC4_SetConfig
- >> TIM_OC3_SetConfig
- >> TIM_OC1_SetConfig

[Called By]

- >> MX_TIM2_Init

HAL_TIM_OC_DelayElapsedCallback (Thumb, 274 bytes, Stack size 32 bytes, main.o(i.HAL_TIM_OC_DelayElapsedCallback))

[Stack]

- Max Depth = 136
- Call Chain = HAL_TIM_OC_DelayElapsedCallback ⇒ adc_scan ⇒ HAL_ADC_PollForConversion ⇒ HAL_RCCEx_GetPeriphCLKFreq

[Calls]

- >> HAL_IWDG_Refresh
- >> adc_scan
- >> __ARM_scalbnf
- >> __aeabi_fmul
- >> __aeabi_ui2f
- >> __aeabi_i2f
- >> __aeabi_f2iz
- >> __aeabi_fsub
- >> __aeabi_fadd
- >> __aeabi_dmul
- >> __aeabi_ui2d
- >> __aeabi_d2iz
- >> __aeabi_dadd

[Called By]

- >> HAL_TIM_IRQHandler

HAL_TIM_OC_Init (Thumb, 90 bytes, Stack size 8 bytes, stm32f1xx_hal_tim.o(i.HAL_TIM_OC_Init))

[Stack]

- Max Depth = 28
- Call Chain = HAL_TIM_OC_Init ⇒ TIM_Base_SetConfig

[Calls]

- >> HAL_TIM_OC_MspInit
- >> TIM_Base_SetConfig

[Called By]

- >> MX_TIM2_Init

HAL_TIM_OC_MspInit (Thumb, 2 bytes, Stack size 0 bytes, stm32f1xx_hal_tim.o(i.HAL_TIM_OC_MspInit))

[Called By]

- >> HAL_TIM_OC_Init

HAL_TIM_OC_Start_IT (Thumb, 184 bytes, Stack size 8 bytes, stm32f1xx_hal_tim.o(i.HAL_TIM_OC_Start_IT))

[Stack]

- Max Depth = 16
- Call Chain = HAL_TIM_OC_Start_IT ⇒ TIM_CCxChannelCmd

[Calls]

- >> TIM_CCxChannelCmd

[Called By]

- >> main

HAL_TIM_PWM_ConfigChannel (Thumb, 198 bytes, Stack size 16 bytes, stm32f1xx_hal_tim.o(i.HAL_TIM_PWM_ConfigChannel))

[Stack]

- Max Depth = 28
- Call Chain = HAL_TIM_PWM_ConfigChannel ⇒ TIM_OC2_SetConfig

[Calls]

- >> TIM_OC2_SetConfig
- >> TIM_OC4_SetConfig
- >> TIM_OC3_SetConfig
- >> TIM_OC1_SetConfig

[Called By]

- >> MX_TIM2_Init

HAL_TIM_PWM_Init (Thumb, 90 bytes, Stack size 8 bytes, stm32f1xx_hal_tim.o(i.HAL_TIM_PWM_Init))

[Stack]

- Max Depth = 28
- Call Chain = HAL_TIM_PWM_Init ⇒ TIM_Base_SetConfig

[Calls]

- >> HAL_TIM_PWM_MspInit
- >> TIM_Base_SetConfig

[Called By]

- >> MX_TIM2_Init

HAL_TIM_PWM_MspInit (Thumb, 2 bytes, Stack size 0 bytes, stm32f1xx_hal_tim.o(i.HAL_TIM_PWM_MspInit))

[Called By]

- >> HAL_TIM_PWM_Init

HAL_TIM_PWM_PulseFinishedCallback (Thumb, 2 bytes, Stack size 0 bytes, stm32f1xx_hal_tim.o(i.HAL_TIM_PWM_PulseFinishedCallback))

[Called By]

- >> HAL_TIM_IRQHandler

HAL_TIM_PWM_Start (Thumb, 144 bytes, Stack size 8 bytes, stm32f1xx_hal_tim.o(i.HAL_TIM_PWM_Start))

[Stack]

- Max Depth = 16
- Call Chain = HAL_TIM_PWM_Start ⇒ TIM_CCxChannelCmd

[Calls]

- >> TIM_CCxChannelCmd

[Called By]

- >> main

HAL_TIM_PeriodElapsedCallback (Thumb, 2 bytes, Stack size 0 bytes, stm32f1xx_hal_tim.o(i.HAL_TIM_PeriodElapsedCallback))

[Called By]

- >> HAL_TIM_IRQHandler

HAL_TIM_TriggerCallback (Thumb, 2 bytes, Stack size 0 bytes, stm32f1xx_hal_tim.o(i.HAL_TIM_TriggerCallback))

[Called By]

- >> HAL_TIM_IRQHandler

HAL_UART_Init (Thumb, 98 bytes, Stack size 16 bytes, stm32f1xx_hal_uart.o(i.HAL_UART_Init))

[Stack]

- Max Depth = 88
- Call Chain = HAL_UART_Init ⇒ HAL_UART_MspInit ⇒ HAL_GPIO_Init

[Calls]

- >> HAL_UART_MspInit
- >> UART_SetConfig

[Called By]

- >> MX_USART1_UART_Init

HAL_UART_MspInit (Thumb, 100 bytes, Stack size 32 bytes, usart.o(i.HAL_UART_MspInit))

[Stack]

- Max Depth = 72
- Call Chain = HAL_UART_MspInit ⇒ HAL_GPIO_Init

[Calls]

- >> HAL_GPIO_Init

[Called By]

- >> HAL_UART_Init

HardFault_Handler (Thumb, 2 bytes, Stack size 0 bytes, stm32f1xx_it.o(i.HardFault_Handler))

[Calls]

- >> HardFault_Handler

[Called By]

- >> HardFault_Handler

[Address Reference Count : 1]

- startup_stm32f103xb.o(RESET)

MX_ADC1_Init (Thumb, 68 bytes, Stack size 24 bytes, adc.o(i.MX_ADC1_Init))

[Stack]

- Max Depth = 112
- Call Chain = MX_ADC1_Init ⇒ HAL_ADC_Init ⇒ HAL_ADC_MspInit ⇒ HAL_GPIO_Init

[Calls]

- >> HAL_ADC_Init
- >> HAL_ADC_ConfigChannel
- >> Error_Handler

[Called By]

- >> main

MX_GPIO_Init (Thumb, 120 bytes, Stack size 40 bytes, gpio.o(i.MX_GPIO_Init))

[Stack]

- Max Depth = 80
- Call Chain = MX_GPIO_Init ⇒ HAL_GPIO_Init

[Calls]

- >> HAL_GPIO_WritePin
- >> HAL_GPIO_Init

[Called By]

- >> main

MX_I2C1_Init (Thumb, 50 bytes, Stack size 8 bytes, i2c.o(i.MX_I2C1_Init))

[Stack]

- Max Depth = 96
- Call Chain = MX_I2C1_Init ⇒ HAL_I2C_Init ⇒ HAL_I2C_MspInit ⇒ HAL_GPIO_Init

[Calls]

- >> HAL_I2C_Init
- >> Error_Handler

[Called By]

- >> oled_show
- >> main

MX_IWDG_Init (Thumb, 36 bytes, Stack size 8 bytes, iwdg.o(i.MX_IWDG_Init))

[Stack]

- Max Depth = 24
- Call Chain = MX_IWDG_Init ⇒ HAL_IWDG_Init

[Calls]

- >> HAL_IWDG_Init
- >> Error_Handler

[Called By]

- >> main

MX_TIM2_Init (Thumb, 190 bytes, Stack size 64 bytes, tim.o(i.MX_TIM2_Init))

[Stack]

- Max Depth = 128
- Call Chain = MX_TIM2_Init ⇒ HAL_TIM_MspPostInit ⇒ HAL_GPIO_Init

[Calls]

- >> HAL_TIM_PWM_Init
- >> HAL_TIM_PWM_ConfigChannel
- >> HAL_TIM_OC_Init
- >> HAL_TIM_OC_ConfigChannel
- >> HAL_TIM_ConfigClockSource
- >> HAL_TIM_Base_Init
- >> HAL_TIMEx_MasterConfigSynchronization
- >> HAL_TIM_MspPostInit
- >> Error_Handler
- >> __aeabi_memclr4

[Called By]

- >> main

MX_USART1_UART_Init (Thumb, 48 bytes, Stack size 8 bytes, usart.o(i.MX_USART1_UART_Init))

[Stack]

- Max Depth = 96
- Call Chain = MX_USART1_UART_Init ⇒ HAL_UART_Init ⇒ HAL_UART_MspInit ⇒ HAL_GPIO_Init

[Calls]

- >> HAL_UART_Init
- >> Error_Handler

[Called By]

- >> main

MemManage_Handler (Thumb, 2 bytes, Stack size 0 bytes, stm32f1xx_it.o(i.MemManage_Handler))

[Calls]

- >> MemManage_Handler

[Called By]

- >> MemManage_Handler

[Address Reference Count : 1]

- startup_stm32f103xb.o(RESET)

NMI_Handler (Thumb, 2 bytes, Stack size 0 bytes, stm32f1xx_it.o(i.NMI_Handler))

[Calls]

- >> NMI_Handler

[Called By]

- >> NMI_Handler

[Address Reference Count : 1]

- startup_stm32f103xb.o(RESET)

OLED_CLS (Thumb, 6 bytes, Stack size 0 bytes, oled.o(i.OLED_CLS))

[Stack]

- Max Depth = 168
- Call Chain = OLED_CLS ⇒ OLED_Fill ⇒ writeDat ⇒ HAL_I2C_Mem_Write ⇒ I2C_RequestMemoryWrite ⇒ I2C_WaitOnMasterAddressFlagUntilTimeout

[Calls]

- >> OLED_Fill

[Called By]

- >> main

OLED_Fill (Thumb, 70 bytes, Stack size 16 bytes, oled.o(i.OLED_Fill))

[Stack]

- Max Depth = 168
- Call Chain = OLED_Fill ⇒ writeDat ⇒ HAL_I2C_Mem_Write ⇒ I2C_RequestMemoryWrite ⇒ I2C_WaitOnMasterAddressFlagUntilTimeout

[Calls]

- >> writeDat
- >> writeCmd

[Called By]

- >> OLED_CLS

OLED_Init (Thumb, 258 bytes, Stack size 8 bytes, oled.o(i.OLED_Init))

[Stack]

- Max Depth = 160
- Call Chain = OLED_Init ⇒ writeCmd ⇒ HAL_I2C_Mem_Write ⇒ I2C_RequestMemoryWrite ⇒ I2C_WaitOnMasterAddressFlagUntilTimeout

[Calls]

- >> HAL_Delay
- >> writeCmd

[Called By]

- >> oled_show
- >> main

OLED_SetPos (Thumb, 46 bytes, Stack size 8 bytes, oled.o(i.OLED_SetPos))

[Stack]

- Max Depth = 160
- Call Chain = OLED_SetPos ⇒ writeCmd ⇒ HAL_I2C_Mem_Write ⇒ I2C_RequestMemoryWrite ⇒ I2C_WaitOnMasterAddressFlagUntilTimeout

[Calls]

- >> writeCmd

[Called By]

- >> OLED_ShowCN

OLED_ShowCN (Thumb, 78 bytes, Stack size 32 bytes, oled.o(i.OLED_ShowCN))

[Stack]

- Max Depth = 192
- Call Chain = OLED_ShowCN ⇒ OLED_SetPos ⇒ writeCmd ⇒ HAL_I2C_Mem_Write ⇒ I2C_RequestMemoryWrite ⇒ I2C_WaitOnMasterAddressFlagUntilTimeout

[Calls]

- >> writeDat
- >> OLED_SetPos

[Called By]

- >> oled_show

PendSV_Handler (Thumb, 2 bytes, Stack size 0 bytes, stm32f1xx_it.o(i.PendSV_Handler))
[Address Reference Count : 1]

- startup_stm32f103xb.o(RESET)

SVC_Handler (Thumb, 2 bytes, Stack size 0 bytes, stm32f1xx_it.o(i.SVC_Handler))
[Address Reference Count : 1]

- startup_stm32f103xb.o(RESET)

SysTick_Handler (Thumb, 4 bytes, Stack size 0 bytes, stm32f1xx_it.o(i.SysTick_Handler))

[Calls]

- >> HAL_IncTick

[Address Reference Count : 1]

- startup_stm32f103xb.o(RESET)

SystemClock_Config (Thumb, 128 bytes, Stack size 88 bytes, main.o(i.SystemClock_Config))

[Stack]

- Max Depth = 152
- Call Chain = SystemClock_Config ⇒ HAL_RCC_ClockConfig ⇒ HAL_InitTick ⇒ HAL_NVIC_SetPriority

[Calls]

- >> HAL_RCC_OscConfig
- >> HAL_RCC_ClockConfig
- >> HAL_RCCEx_PeriphCLKConfig
- >> __aeabi_memclr4

[Called By]

- >> main

SystemInit (Thumb, 2 bytes, Stack size 0 bytes, system_stm32f1xx.o(i.SystemInit))
[Address Reference Count : 1]

- startup_stm32f103xb.o(.text)

TIM2_IRQHandler (Thumb, 6 bytes, Stack size 0 bytes, stm32f1xx_it.o(i.TIM2_IRQHandler))

[Stack]

- Max Depth = 152
- Call Chain = TIM2_IRQHandler ⇒ HAL_TIM_IRQHandler ⇒ HAL_TIM_OC_DelayElapsedCallback ⇒ adc_scan ⇒ HAL_ADC_PollForConversion ⇒ HAL_RCCEx_GetPeriphCLKFreq

[Calls]

- >> HAL_TIM_IRQHandler

[Address Reference Count : 1]

- startup_stm32f103xb.o(RESET)

TIM_Base_SetConfig (Thumb, 94 bytes, Stack size 20 bytes, stm32f1xx_hal_tim.o(i.TIM_Base_SetConfig))

[Stack]

- Max Depth = 20
- Call Chain = TIM_Base_SetConfig

[Called By]

- >> HAL_TIM_PWM_Init
- >> HAL_TIM_OC_Init
- >> HAL_TIM_Base_Init

TIM_CCxChannelCmd (Thumb, 26 bytes, Stack size 8 bytes, stm32f1xx_hal_tim.o(i.TIM_CCxChannelCmd))

[Stack]

- Max Depth = 8
- Call Chain = TIM_CCxChannelCmd

[Called By]

- >> HAL_TIM_PWM_Start
- >> HAL_TIM_OC_Start_IT

TIM_ETR_SetConfig (Thumb, 20 bytes, Stack size 8 bytes, stm32f1xx_hal_tim.o(i.TIM_ETR_SetConfig))

[Stack]

- Max Depth = 8
- Call Chain = TIM_ETR_SetConfig

[Called By]

- >> HAL_TIM_ConfigClockSource

TIM_OC2_SetConfig (Thumb, 84 bytes, Stack size 12 bytes, stm32f1xx_hal_tim.o(i.TIM_OC2_SetConfig))

[Stack]

- Max Depth = 12
- Call Chain = TIM_OC2_SetConfig

[Called By]

- >> HAL_TIM_PWM_ConfigChannel
- >> HAL_TIM_OC_ConfigChannel

UsageFault_Handler (Thumb, 2 bytes, Stack size 0 bytes, stm32f1xx_it.o(i.UsageFault_Handler))

[Calls]

- >> UsageFault_Handler

[Called By]

- >> UsageFault_Handler

[Address Reference Count : 1]

- startup_stm32f103xb.o(RESET)

adc_scan (Thumb, 230 bytes, Stack size 40 bytes, main.o(i.adc_scan))

[Stack]

- Max Depth = 104
- Call Chain = adc_scan ⇒ HAL_ADC_PollForConversion ⇒ HAL_RCCEx_GetPeriphCLKFreq

[Calls]

- >> HAL_ADC_Stop
- >> HAL_ADC_Start
- >> HAL_ADC_PollForConversion
- >> HAL_ADC_GetValue
- >> ADC_Select_CH
- >> __aeabi_dmul
- >> __aeabi_ui2d
- >> __aeabi_d2uiz
- >> __aeabi_dadd

[Called By]

- >> HAL_TIM_OC_DelayElapsedCallback

main (Thumb, 98 bytes, Stack size 0 bytes, main.o(i.main))

[Stack]

- Max Depth = 216
- Call Chain = main ⇒ oled_show ⇒ OLED_ShowCN ⇒ OLED_SetPos ⇒ writeCmd ⇒ HAL_I2C_Mem_Write ⇒ I2C_RequestMemoryWrite ⇒ I2C_WaitOnMasterAddressFlagUntilTimeout

[Calls]

- >> OLED_Init
- >> OLED_CLS
- >> MX_USART1_UART_Init
- >> MX_TIM2_Init
- >> MX_IWDG_Init
- >> MX_I2C1_Init
- >> MX_GPIO_Init
- >> MX_ADC1_Init
- >> HAL_TIM_PWM_Start
- >> HAL_TIM_OC_Start_IT
- >> HAL_TIM_Base_Start_IT
- >> HAL_Init
- >> HAL_IWDG_Refresh
- >> HAL_GPIO_TogglePin
- >> HAL_Delay
- >> oled_show
- >> SystemClock_Config

[Called By]

- >> __rt_entry_main

oled_show (Thumb, 314 bytes, Stack size 24 bytes, main.o(i.oled_show))

[Stack]

- Max Depth = 216
- Call Chain = oled_show ⇒ OLED_ShowCN ⇒ OLED_SetPos ⇒ writeCmd ⇒ HAL_I2C_Mem_Write ⇒ I2C_RequestMemoryWrite ⇒ I2C_WaitOnMasterAddressFlagUntilTimeout

[Calls]

- >> OLED_ShowCN
- >> OLED_Init
- >> MX_I2C1_Init
- >> HAL_I2C_MspInit
- >> HAL_I2C_MspDeInit

[Called By]

- >> main

writeCmd (Thumb, 30 bytes, Stack size 24 bytes, oled.o(i.writeCmd))

[Stack]

- Max Depth = 152
- Call Chain = writeCmd ⇒ HAL_I2C_Mem_Write ⇒ I2C_RequestMemoryWrite ⇒ I2C_WaitOnMasterAddressFlagUntilTimeout

[Calls]

- >> HAL_I2C_Mem_Write

[Called By]

- >> OLED_Init
- >> OLED_SetPos
- >> OLED_Fill

writeDat (Thumb, 30 bytes, Stack size 24 bytes, oled.o(i.writeDat))

[Stack]

- Max Depth = 152
- Call Chain = writeDat ⇒ HAL_I2C_Mem_Write ⇒ I2C_RequestMemoryWrite ⇒ I2C_WaitOnMasterAddressFlagUntilTimeout

[Calls]

- >> HAL_I2C_Mem_Write

[Called By]

- >> OLED_ShowCN
- >> OLED_Fill

__aeabi_dadd (Thumb, 0 bytes, Stack size 16 bytes, daddsub_clz.o(x$fpl$dadd))

[Stack]

- Max Depth = 16
- Call Chain = __aeabi_dadd

[Called By]

- >> adc_scan
- >> HAL_TIM_OC_DelayElapsedCallback

_dadd (Thumb, 332 bytes, Stack size 16 bytes, daddsub_clz.o(x$fpl$dadd), UNUSED)

[Calls]

- >> __fpl_dretinf
- >> __fpl_dnaninf
- >> _dsub1

__aeabi_d2iz (Thumb, 0 bytes, Stack size 32 bytes, dfix.o(x$fpl$dfix))

[Stack]

- Max Depth = 32
- Call Chain = __aeabi_d2iz

[Called By]

- >> HAL_TIM_OC_DelayElapsedCallback

_dfix (Thumb, 94 bytes, Stack size 32 bytes, dfix.o(x$fpl$dfix), UNUSED)

[Calls]

- >> __fpl_dnaninf

__aeabi_d2uiz (Thumb, 0 bytes, Stack size 32 bytes, dfixu.o(x$fpl$dfixu))

[Stack]

- Max Depth = 32
- Call Chain = __aeabi_d2uiz

[Called By]

- >> adc_scan

_dfixu (Thumb, 90 bytes, Stack size 32 bytes, dfixu.o(x$fpl$dfixu), UNUSED)

[Calls]

- >> __fpl_dnaninf

__aeabi_ui2d (Thumb, 0 bytes, Stack size 0 bytes, dflt_clz.o(x$fpl$dfltu))

[Called By]

- >> adc_scan
- >> HAL_TIM_OC_DelayElapsedCallback

_dfltu (Thumb, 38 bytes, Stack size 0 bytes, dflt_clz.o(x$fpl$dfltu), UNUSED)

__aeabi_dmul (Thumb, 0 bytes, Stack size 32 bytes, dmul.o(x$fpl$dmul))

[Stack]

- Max Depth = 32
- Call Chain = __aeabi_dmul

[Called By]

- >> adc_scan
- >> HAL_TIM_OC_DelayElapsedCallback

_dmul (Thumb, 332 bytes, Stack size 32 bytes, dmul.o(x$fpl$dmul), UNUSED)

[Calls]

- >> __fpl_dretinf
- >> __fpl_dnaninf

__fpl_dnaninf (Thumb, 156 bytes, Stack size 16 bytes, dnaninf.o(x$fpl$dnaninf), UNUSED)

[Called By]

- >> _dmul
- >> _dfixu
- >> _dfix
- >> _dsub
- >> _dadd

__fpl_dretinf (Thumb, 12 bytes, Stack size 0 bytes, dretinf.o(x$fpl$dretinf), UNUSED)

[Called By]

- >> _dmul
- >> _dadd

__aeabi_dsub (Thumb, 0 bytes, Stack size 32 bytes, daddsub_clz.o(x$fpl$dsub), UNUSED)

_dsub (Thumb, 464 bytes, Stack size 32 bytes, daddsub_clz.o(x$fpl$dsub), UNUSED)

[Calls]

- >> __fpl_dnaninf
- >> _dadd1

__aeabi_fadd (Thumb, 0 bytes, Stack size 16 bytes, faddsub_clz.o(x$fpl$fadd))

[Stack]

- Max Depth = 16
- Call Chain = __aeabi_fadd

[Called By]

- >> HAL_TIM_OC_DelayElapsedCallback

_fadd (Thumb, 196 bytes, Stack size 16 bytes, faddsub_clz.o(x$fpl$fadd), UNUSED)

[Calls]

- >> __fpl_fretinf
- >> __fpl_fnaninf
- >> _fsub1

__fpl_fcheck_NaN1 (Thumb, 6 bytes, Stack size 0 bytes, fcheck1.o(x$fpl$fcheck1))

[Calls]

- >> __fpl_return_NaN

[Called By]

- >> __ARM_scalbnf

__aeabi_f2iz (Thumb, 0 bytes, Stack size 16 bytes, ffix.o(x$fpl$ffix))

[Stack]

- Max Depth = 16
- Call Chain = __aeabi_f2iz

[Called By]

- >> HAL_TIM_OC_DelayElapsedCallback

_ffix (Thumb, 54 bytes, Stack size 16 bytes, ffix.o(x$fpl$ffix), UNUSED)

[Calls]

- >> __fpl_fnaninf

__aeabi_i2f (Thumb, 0 bytes, Stack size 0 bytes, fflt_clz.o(x$fpl$fflt))

[Called By]

- >> HAL_TIM_OC_DelayElapsedCallback

_fflt (Thumb, 48 bytes, Stack size 0 bytes, fflt_clz.o(x$fpl$fflt), UNUSED)

__aeabi_ui2f (Thumb, 0 bytes, Stack size 0 bytes, fflt_clz.o(x$fpl$ffltu))

[Called By]

- >> HAL_TIM_OC_DelayElapsedCallback

_ffltu (Thumb, 38 bytes, Stack size 0 bytes, fflt_clz.o(x$fpl$ffltu), UNUSED)

__aeabi_fmul (Thumb, 0 bytes, Stack size 16 bytes, fmul.o(x$fpl$fmul))

[Stack]

- Max Depth = 16
- Call Chain = __aeabi_fmul

[Called By]

- >> HAL_TIM_OC_DelayElapsedCallback

_fmul (Thumb, 258 bytes, Stack size 16 bytes, fmul.o(x$fpl$fmul), UNUSED)

[Calls]

- >> __fpl_fretinf
- >> __fpl_fnaninf

__fpl_fnaninf (Thumb, 140 bytes, Stack size 8 bytes, fnaninf.o(x$fpl$fnaninf), UNUSED)

[Called By]

- >> _fmul
- >> _ffix
- >> _fsub
- >> _fadd

__fpl_fretinf (Thumb, 10 bytes, Stack size 0 bytes, fretinf.o(x$fpl$fretinf), UNUSED)

[Called By]

- >> _fmul
- >> _fadd

__aeabi_fsub (Thumb, 0 bytes, Stack size 16 bytes, faddsub_clz.o(x$fpl$fsub))

[Stack]

- Max Depth = 16
- Call Chain = __aeabi_fsub

[Called By]

- >> HAL_TIM_OC_DelayElapsedCallback

_fsub (Thumb, 234 bytes, Stack size 16 bytes, faddsub_clz.o(x$fpl$fsub), UNUSED)

[Calls]

- >> __fpl_fnaninf
- >> _fadd1

__fpl_return_NaN (Thumb, 100 bytes, Stack size 0 bytes, retnan.o(x$fpl$retnan))

[Calls]

- >> __fpl_cmpreturn

[Called By]

- >> __fpl_fcheck_NaN1

__ARM_scalbnf (Thumb, 76 bytes, Stack size 0 bytes, scalbnf.o(x$fpl$scalbnf))

[Calls]

- >> __fpl_fcheck_NaN1

[Called By]

- >> HAL_TIM_OC_DelayElapsedCallback

__fpl_cmpreturn (Thumb, 48 bytes, Stack size 0 bytes, trapv.o(x$fpl$trapveneer))

[Called By]

- >> __fpl_return_NaN

### Local Symbols

__NVIC_SetPriority (Thumb, 32 bytes, Stack size 0 bytes, stm32f1xx_hal_cortex.o(i.__NVIC_SetPriority))

[Called By]

- >> HAL_NVIC_SetPriority
- >> HAL_SYSTICK_Config

I2C_IsAcknowledgeFailed (Thumb, 46 bytes, Stack size 0 bytes, stm32f1xx_hal_i2c.o(i.I2C_IsAcknowledgeFailed))

[Called By]

- >> I2C_WaitOnTXEFlagUntilTimeout
- >> I2C_WaitOnBTFFlagUntilTimeout

I2C_RequestMemoryWrite (Thumb, 162 bytes, Stack size 32 bytes, stm32f1xx_hal_i2c.o(i.I2C_RequestMemoryWrite))

[Stack]

- Max Depth = 64
- Call Chain = I2C_RequestMemoryWrite ⇒ I2C_WaitOnMasterAddressFlagUntilTimeout

[Calls]

- >> I2C_WaitOnTXEFlagUntilTimeout
- >> I2C_WaitOnMasterAddressFlagUntilTimeout
- >> I2C_WaitOnFlagUntilTimeout

[Called By]

- >> HAL_I2C_Mem_Write

I2C_WaitOnBTFFlagUntilTimeout (Thumb, 76 bytes, Stack size 16 bytes, stm32f1xx_hal_i2c.o(i.I2C_WaitOnBTFFlagUntilTimeout))

[Stack]

- Max Depth = 16
- Call Chain = I2C_WaitOnBTFFlagUntilTimeout

[Calls]

- >> HAL_GetTick
- >> I2C_IsAcknowledgeFailed

[Called By]

- >> HAL_I2C_Mem_Write

I2C_WaitOnFlagUntilTimeout (Thumb, 104 bytes, Stack size 32 bytes, stm32f1xx_hal_i2c.o(i.I2C_WaitOnFlagUntilTimeout))

[Stack]

- Max Depth = 32
- Call Chain = I2C_WaitOnFlagUntilTimeout

[Calls]

- >> HAL_GetTick

[Called By]

- >> HAL_I2C_Mem_Write
- >> I2C_RequestMemoryWrite

I2C_WaitOnMasterAddressFlagUntilTimeout (Thumb, 150 bytes, Stack size 32 bytes, stm32f1xx_hal_i2c.o(i.I2C_WaitOnMasterAddressFlagUntilTimeout))

[Stack]

- Max Depth = 32
- Call Chain = I2C_WaitOnMasterAddressFlagUntilTimeout

[Calls]

- >> HAL_GetTick

[Called By]

- >> I2C_RequestMemoryWrite

I2C_WaitOnTXEFlagUntilTimeout (Thumb, 76 bytes, Stack size 16 bytes, stm32f1xx_hal_i2c.o(i.I2C_WaitOnTXEFlagUntilTimeout))

[Stack]

- Max Depth = 16
- Call Chain = I2C_WaitOnTXEFlagUntilTimeout

[Calls]

- >> HAL_GetTick
- >> I2C_IsAcknowledgeFailed

[Called By]

- >> HAL_I2C_Mem_Write
- >> I2C_RequestMemoryWrite

TIM_ITRx_SetConfig (Thumb, 16 bytes, Stack size 0 bytes, stm32f1xx_hal_tim.o(i.TIM_ITRx_SetConfig))

[Called By]

- >> HAL_TIM_ConfigClockSource

TIM_OC1_SetConfig (Thumb, 74 bytes, Stack size 12 bytes, stm32f1xx_hal_tim.o(i.TIM_OC1_SetConfig))

[Stack]

- Max Depth = 12
- Call Chain = TIM_OC1_SetConfig

[Called By]

- >> HAL_TIM_PWM_ConfigChannel
- >> HAL_TIM_OC_ConfigChannel

TIM_OC3_SetConfig (Thumb, 82 bytes, Stack size 12 bytes, stm32f1xx_hal_tim.o(i.TIM_OC3_SetConfig))

[Stack]

- Max Depth = 12
- Call Chain = TIM_OC3_SetConfig

[Called By]

- >> HAL_TIM_PWM_ConfigChannel
- >> HAL_TIM_OC_ConfigChannel

TIM_OC4_SetConfig (Thumb, 64 bytes, Stack size 12 bytes, stm32f1xx_hal_tim.o(i.TIM_OC4_SetConfig))

[Stack]

- Max Depth = 12
- Call Chain = TIM_OC4_SetConfig

[Called By]

- >> HAL_TIM_PWM_ConfigChannel
- >> HAL_TIM_OC_ConfigChannel

TIM_TI1_ConfigInputStage (Thumb, 34 bytes, Stack size 8 bytes, stm32f1xx_hal_tim.o(i.TIM_TI1_ConfigInputStage))

[Stack]

- Max Depth = 8
- Call Chain = TIM_TI1_ConfigInputStage

[Called By]

- >> HAL_TIM_ConfigClockSource

TIM_TI2_ConfigInputStage (Thumb, 36 bytes, Stack size 8 bytes, stm32f1xx_hal_tim.o(i.TIM_TI2_ConfigInputStage))

[Stack]

- Max Depth = 8
- Call Chain = TIM_TI2_ConfigInputStage

[Called By]

- >> HAL_TIM_ConfigClockSource

UART_SetConfig (Thumb, 178 bytes, Stack size 16 bytes, stm32f1xx_hal_uart.o(i.UART_SetConfig))

[Stack]

- Max Depth = 16
- Call Chain = UART_SetConfig

[Calls]

- >> HAL_RCC_GetPCLK2Freq
- >> HAL_RCC_GetPCLK1Freq

[Called By]

- >> HAL_UART_Init

_dadd1 (Thumb, 0 bytes, Stack size unknown bytes, daddsub_clz.o(x$fpl$dadd), UNUSED)

[Called By]

- >> _dsub

_dsub1 (Thumb, 0 bytes, Stack size unknown bytes, daddsub_clz.o(x$fpl$dsub), UNUSED)

[Called By]

- >> _dadd

_fadd1 (Thumb, 0 bytes, Stack size unknown bytes, faddsub_clz.o(x$fpl$fadd), UNUSED)

[Called By]

- >> _fsub

_fsub1 (Thumb, 0 bytes, Stack size unknown bytes, faddsub_clz.o(x$fpl$fsub), UNUSED)

[Called By]

- >> _fadd

### Undefined Global Symbols

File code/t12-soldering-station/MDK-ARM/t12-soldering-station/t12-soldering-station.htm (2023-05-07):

# Static Call Graph for image t12-soldering-station\t12-soldering-station.axf

#<CALLGRAPH># ARM Linker, 5060750: Last Updated: Fri May 05 01:42:48 2023

### Maximum Stack Usage = 216 bytes + Unknown(Functions without stacksize, Cycles, Untraceable Function Pointers)

### Call chain for Maximum Stack Depth:

__rt_entry_main ⇒ main ⇒ oled_show ⇒ OLED_ShowCN ⇒ OLED_SetPos ⇒ WriteCmd ⇒ HAL_I2C_Mem_Write ⇒ I2C_RequestMemoryWrite ⇒ I2C_WaitOnMasterAddressFlagUntilTimeout

### Functions with no stack information

- __user_initial_stackheap

### Mutually Recursive functions

- ADC1_2_IRQHandler ⇒ ADC1_2_IRQHandler
- BusFault_Handler ⇒ BusFault_Handler
- HardFault_Handler ⇒ HardFault_Handler
- MemManage_Handler ⇒ MemManage_Handler
- NMI_Handler ⇒ NMI_Handler
- UsageFault_Handler ⇒ UsageFault_Handler

### Function Pointers

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

### Global Symbols

__main (Thumb, 8 bytes, Stack size 0 bytes, __main.o(!!!main))

[Calls]

- >> __scatterload
- >> __rt_entry

__scatterload (Thumb, 0 bytes, Stack size unknown bytes, __scatter.o(!!!scatter))

[Called By]

- >> __main

__scatterload_rt2 (Thumb, 44 bytes, Stack size unknown bytes, __scatter.o(!!!scatter), UNUSED)

[Calls]

- >> __rt_entry

__scatterload_rt2_thumb_only (Thumb, 0 bytes, Stack size unknown bytes, __scatter.o(!!!scatter), UNUSED)

__scatterload_null (Thumb, 0 bytes, Stack size unknown bytes, __scatter.o(!!!scatter), UNUSED)

__decompress (Thumb, 90 bytes, Stack size unknown bytes, __dczerorl2.o(!!dczerorl2), UNUSED)

__decompress1 (Thumb, 0 bytes, Stack size unknown bytes, __dczerorl2.o(!!dczerorl2), UNUSED)

__scatterload_zeroinit (Thumb, 28 bytes, Stack size unknown bytes, __scatter_zi.o(!!handler_zi), UNUSED)

__rt_lib_init (Thumb, 0 bytes, Stack size unknown bytes, libinit.o(.ARM.Collect$$libinit$$00000000))

[Called By]

- >> __rt_entry_li

__rt_lib_init_alloca_1 (Thumb, 0 bytes, Stack size unknown bytes, libinit2.o(.ARM.Collect$$libinit$$0000002E))

__rt_lib_init_argv_1 (Thumb, 0 bytes, Stack size unknown bytes, libinit2.o(.ARM.Collect$$libinit$$0000002C))

__rt_lib_init_atexit_1 (Thumb, 0 bytes, Stack size unknown bytes, libinit2.o(.ARM.Collect$$libinit$$0000001B))

__rt_lib_init_clock_1 (Thumb, 0 bytes, Stack size unknown bytes, libinit2.o(.ARM.Collect$$libinit$$00000021))

__rt_lib_init_cpp_1 (Thumb, 0 bytes, Stack size unknown bytes, libinit2.o(.ARM.Collect$$libinit$$00000032))

__rt_lib_init_exceptions_1 (Thumb, 0 bytes, Stack size unknown bytes, libinit2.o(.ARM.Collect$$libinit$$00000030))

__rt_lib_init_fp_1 (Thumb, 0 bytes, Stack size unknown bytes, libinit2.o(.ARM.Collect$$libinit$$00000002))

__rt_lib_init_fp_trap_1 (Thumb, 0 bytes, Stack size unknown bytes, libinit2.o(.ARM.Collect$$libinit$$0000001F))

__rt_lib_init_getenv_1 (Thumb, 0 bytes, Stack size unknown bytes, libinit2.o(.ARM.Collect$$libinit$$00000023))

__rt_lib_init_heap_1 (Thumb, 0 bytes, Stack size unknown bytes, libinit2.o(.ARM.Collect$$libinit$$0000000A))

__rt_lib_init_lc_collate_1 (Thumb, 0 bytes, Stack size unknown bytes, libinit2.o(.ARM.Collect$$libinit$$00000011))

__rt_lib_init_lc_ctype_1 (Thumb, 0 bytes, Stack size unknown bytes, libinit2.o(.ARM.Collect$$libinit$$00000013))

__rt_lib_init_lc_monetary_1 (Thumb, 0 bytes, Stack size unknown bytes, libinit2.o(.ARM.Collect$$libinit$$00000015))

__rt_lib_init_lc_numeric_1 (Thumb, 0 bytes, Stack size unknown bytes, libinit2.o(.ARM.Collect$$libinit$$00000017))

__rt_lib_init_lc_time_1 (Thumb, 0 bytes, Stack size unknown bytes, libinit2.o(.ARM.Collect$$libinit$$00000019))

__rt_lib_init_preinit_1 (Thumb, 0 bytes, Stack size unknown bytes, libinit2.o(.ARM.Collect$$libinit$$00000004))

__rt_lib_init_rand_1 (Thumb, 0 bytes, Stack size unknown bytes, libinit2.o(.ARM.Collect$$libinit$$0000000E))

__rt_lib_init_return (Thumb, 0 bytes, Stack size unknown bytes, libinit2.o(.ARM.Collect$$libinit$$00000033))

__rt_lib_init_signal_1 (Thumb, 0 bytes, Stack size unknown bytes, libinit2.o(.ARM.Collect$$libinit$$0000001D))

__rt_lib_init_stdio_1 (Thumb, 0 bytes, Stack size unknown bytes, libinit2.o(.ARM.Collect$$libinit$$00000025))

__rt_lib_init_user_alloc_1 (Thumb, 0 bytes, Stack size unknown bytes, libinit2.o(.ARM.Collect$$libinit$$0000000C))

__rt_lib_shutdown (Thumb, 0 bytes, Stack size unknown bytes, libshutdown.o(.ARM.Collect$$libshutdown$$00000000))

[Called By]

- >> __rt_exit_ls

__rt_lib_shutdown_cpp_1 (Thumb, 0 bytes, Stack size unknown bytes, libshutdown2.o(.ARM.Collect$$libshutdown$$00000002))

__rt_lib_shutdown_fp_trap_1 (Thumb, 0 bytes, Stack size unknown bytes, libshutdown2.o(.ARM.Collect$$libshutdown$$00000007))

__rt_lib_shutdown_heap_1 (Thumb, 0 bytes, Stack size unknown bytes, libshutdown2.o(.ARM.Collect$$libshutdown$$0000000F))

__rt_lib_shutdown_return (Thumb, 0 bytes, Stack size unknown bytes, libshutdown2.o(.ARM.Collect$$libshutdown$$00000010))

__rt_lib_shutdown_signal_1 (Thumb, 0 bytes, Stack size unknown bytes, libshutdown2.o(.ARM.Collect$$libshutdown$$0000000A))

__rt_lib_shutdown_stdio_1 (Thumb, 0 bytes, Stack size unknown bytes, libshutdown2.o(.ARM.Collect$$libshutdown$$00000004))

__rt_lib_shutdown_user_alloc_1 (Thumb, 0 bytes, Stack size unknown bytes, libshutdown2.o(.ARM.Collect$$libshutdown$$0000000C))

__rt_entry (Thumb, 0 bytes, Stack size unknown bytes, __rtentry.o(.ARM.Collect$$rtentry$$00000000))

[Called By]

- >> __scatterload_rt2
- >> __main

__rt_entry_presh_1 (Thumb, 0 bytes, Stack size unknown bytes, __rtentry2.o(.ARM.Collect$$rtentry$$00000002))

__rt_entry_sh (Thumb, 0 bytes, Stack size unknown bytes, __rtentry4.o(.ARM.Collect$$rtentry$$00000004))

[Stack]

- Max Depth = 8 + Unknown Stack Size
- Call Chain = __rt_entry_sh ⇒ __user_setup_stackheap

[Calls]

- >> __user_setup_stackheap

__rt_entry_li (Thumb, 0 bytes, Stack size unknown bytes, __rtentry2.o(.ARM.Collect$$rtentry$$0000000A))

[Calls]

- >> __rt_lib_init

__rt_entry_postsh_1 (Thumb, 0 bytes, Stack size unknown bytes, __rtentry2.o(.ARM.Collect$$rtentry$$00000009))

__rt_entry_main (Thumb, 0 bytes, Stack size unknown bytes, __rtentry2.o(.ARM.Collect$$rtentry$$0000000D))

[Stack]

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

[Calls]

- >> main
- >> exit

__rt_entry_postli_1 (Thumb, 0 bytes, Stack size unknown bytes, __rtentry2.o(.ARM.Collect$$rtentry$$0000000C))

__rt_exit (Thumb, 0 bytes, Stack size unknown bytes, rtexit.o(.ARM.Collect$$rtexit$$00000000))

[Called By]

- >> exit

__rt_exit_ls (Thumb, 0 bytes, Stack size unknown bytes, rtexit2.o(.ARM.Collect$$rtexit$$00000003))

[Calls]

- >> __rt_lib_shutdown

__rt_exit_prels_1 (Thumb, 0 bytes, Stack size unknown bytes, rtexit2.o(.ARM.Collect$$rtexit$$00000002))

__rt_exit_exit (Thumb, 0 bytes, Stack size unknown bytes, rtexit2.o(.ARM.Collect$$rtexit$$00000004))

[Calls]

- >> _sys_exit

Reset_Handler (Thumb, 8 bytes, Stack size 0 bytes, startup_stm32f103xb.o(.text))
[Address Reference Count : 1]

- startup_stm32f103xb.o(RESET)

ADC1_2_IRQHandler (Thumb, 0 bytes, Stack size 0 bytes, startup_stm32f103xb.o(.text))

[Calls]

- >> ADC1_2_IRQHandler

[Called By]

- >> ADC1_2_IRQHandler

[Address Reference Count : 1]

- startup_stm32f103xb.o(RESET)

CAN1_RX1_IRQHandler (Thumb, 0 bytes, Stack size 0 bytes, startup_stm32f103xb.o(.text))
[Address Reference Count : 1]

- startup_stm32f103xb.o(RESET)

CAN1_SCE_IRQHandler (Thumb, 0 bytes, Stack size 0 bytes, startup_stm32f103xb.o(.text))
[Address Reference Count : 1]

- startup_stm32f103xb.o(RESET)

DMA1_Channel1_IRQHandler (Thumb, 0 bytes, Stack size 0 bytes, startup_stm32f103xb.o(.text))
[Address Reference Count : 1]

- startup_stm32f103xb.o(RESET)

DMA1_Channel2_IRQHandler (Thumb, 0 bytes, Stack size 0 bytes, startup_stm32f103xb.o(.text))
[Address Reference Count : 1]

- startup_stm32f103xb.o(RESET)

DMA1_Channel3_IRQHandler (Thumb, 0 bytes, Stack size 0 bytes, startup_stm32f103xb.o(.text))
[Address Reference Count : 1]

- startup_stm32f103xb.o(RESET)

DMA1_Channel4_IRQHandler (Thumb, 0 bytes, Stack size 0 bytes, startup_stm32f103xb.o(.text))
[Address Reference Count : 1]

- startup_stm32f103xb.o(RESET)

DMA1_Channel5_IRQHandler (Thumb, 0 bytes, Stack size 0 bytes, startup_stm32f103xb.o(.text))
[Address Reference Count : 1]

- startup_stm32f103xb.o(RESET)

DMA1_Channel6_IRQHandler (Thumb, 0 bytes, Stack size 0 bytes, startup_stm32f103xb.o(.text))
[Address Reference Count : 1]

- startup_stm32f103xb.o(RESET)

DMA1_Channel7_IRQHandler (Thumb, 0 bytes, Stack size 0 bytes, startup_stm32f103xb.o(.text))
[Address Reference Count : 1]

- startup_stm32f103xb.o(RESET)

EXTI0_IRQHandler (Thumb, 0 bytes, Stack size 0 bytes, startup_stm32f103xb.o(.text))
[Address Reference Count : 1]

- startup_stm32f103xb.o(RESET)

EXTI15_10_IRQHandler (Thumb, 0 bytes, Stack size 0 bytes, startup_stm32f103xb.o(.text))
[Address Reference Count : 1]

- startup_stm32f103xb.o(RESET)

EXTI1_IRQHandler (Thumb, 0 bytes, Stack size 0 bytes, startup_stm32f103xb.o(.text))
[Address Reference Count : 1]

- startup_stm32f103xb.o(RESET)

EXTI2_IRQHandler (Thumb, 0 bytes, Stack size 0 bytes, startup_stm32f103xb.o(.text))
[Address Reference Count : 1]

- startup_stm32f103xb.o(RESET)

EXTI3_IRQHandler (Thumb, 0 bytes, Stack size 0 bytes, startup_stm32f103xb.o(.text))
[Address Reference Count : 1]

- startup_stm32f103xb.o(RESET)

EXTI4_IRQHandler (Thumb, 0 bytes, Stack size 0 bytes, startup_stm32f103xb.o(.text))
[Address Reference Count : 1]

- startup_stm32f103xb.o(RESET)

EXTI9_5_IRQHandler (Thumb, 0 bytes, Stack size 0 bytes, startup_stm32f103xb.o(.text))
[Address Reference Count : 1]

- startup_stm32f103xb.o(RESET)

FLASH_IRQHandler (Thumb, 0 bytes, Stack size 0 bytes, startup_stm32f103xb.o(.text))
[Address Reference Count : 1]

- startup_stm32f103xb.o(RESET)

I2C1_ER_IRQHandler (Thumb, 0 bytes, Stack size 0 bytes, startup_stm32f103xb.o(.text))
[Address Reference Count : 1]

- startup_stm32f103xb.o(RESET)

I2C1_EV_IRQHandler (Thumb, 0 bytes, Stack size 0 bytes, startup_stm32f103xb.o(.text))
[Address Reference Count : 1]

- startup_stm32f103xb.o(RESET)

I2C2_ER_IRQHandler (Thumb, 0 bytes, Stack size 0 bytes, startup_stm32f103xb.o(.text))
[Address Reference Count : 1]

- startup_stm32f103xb.o(RESET)

I2C2_EV_IRQHandler (Thumb, 0 bytes, Stack size 0 bytes, startup_stm32f103xb.o(.text))
[Address Reference Count : 1]

- startup_stm32f103xb.o(RESET)

PVD_IRQHandler (Thumb, 0 bytes, Stack size 0 bytes, startup_stm32f103xb.o(.text))
[Address Reference Count : 1]

- startup_stm32f103xb.o(RESET)

RCC_IRQHandler (Thumb, 0 bytes, Stack size 0 bytes, startup_stm32f103xb.o(.text))
[Address Reference Count : 1]

- startup_stm32f103xb.o(RESET)

RTC_Alarm_IRQHandler (Thumb, 0 bytes, Stack size 0 bytes, startup_stm32f103xb.o(.text))
[Address Reference Count : 1]

- startup_stm32f103xb.o(RESET)

RTC_IRQHandler (Thumb, 0 bytes, Stack size 0 bytes, startup_stm32f103xb.o(.text))
[Address Reference Count : 1]

- startup_stm32f103xb.o(RESET)

SPI1_IRQHandler (Thumb, 0 bytes, Stack size 0 bytes, startup_stm32f103xb.o(.text))
[Address Reference Count : 1]

- startup_stm32f103xb.o(RESET)

SPI2_IRQHandler (Thumb, 0 bytes, Stack size 0 bytes, startup_stm32f103xb.o(.text))
[Address Reference Count : 1]

- startup_stm32f103xb.o(RESET)

TAMPER_IRQHandler (Thumb, 0 bytes, Stack size 0 bytes, startup_stm32f103xb.o(.text))
[Address Reference Count : 1]

- startup_stm32f103xb.o(RESET)

TIM1_BRK_IRQHandler (Thumb, 0 bytes, Stack size 0 bytes, startup_stm32f103xb.o(.text))
[Address Reference Count : 1]

- startup_stm32f103xb.o(RESET)

TIM1_CC_IRQHandler (Thumb, 0 bytes, Stack size 0 bytes, startup_stm32f103xb.o(.text))
[Address Reference Count : 1]

- startup_stm32f103xb.o(RESET)

TIM1_TRG_COM_IRQHandler (Thumb, 0 bytes, Stack size 0 bytes, startup_stm32f103xb.o(.text))
[Address Reference Count : 1]

- startup_stm32f103xb.o(RESET)

TIM1_UP_IRQHandler (Thumb, 0 bytes, Stack size 0 bytes, startup_stm32f103xb.o(.text))
[Address Reference Count : 1]

- startup_stm32f103xb.o(RESET)

TIM3_IRQHandler (Thumb, 0 bytes, Stack size 0 bytes, startup_stm32f103xb.o(.text))
[Address Reference Count : 1]

- startup_stm32f103xb.o(RESET)

TIM4_IRQHandler (Thumb, 0 bytes, Stack size 0 bytes, startup_stm32f103xb.o(.text))
[Address Reference Count : 1]

- startup_stm32f103xb.o(RESET)

USART1_IRQHandler (Thumb, 0 bytes, Stack size 0 bytes, startup_stm32f103xb.o(.text))
[Address Reference Count : 1]

- startup_stm32f103xb.o(RESET)

USART2_IRQHandler (Thumb, 0 bytes, Stack size 0 bytes, startup_stm32f103xb.o(.text))
[Address Reference Count : 1]

- startup_stm32f103xb.o(RESET)

USART3_IRQHandler (Thumb, 0 bytes, Stack size 0 bytes, startup_stm32f103xb.o(.text))
[Address Reference Count : 1]

- startup_stm32f103xb.o(RESET)

USBWakeUp_IRQHandler (Thumb, 0 bytes, Stack size 0 bytes, startup_stm32f103xb.o(.text))
[Address Reference Count : 1]

- startup_stm32f103xb.o(RESET)

USB_HP_CAN1_TX_IRQHandler (Thumb, 0 bytes, Stack size 0 bytes, startup_stm32f103xb.o(.text))
[Address Reference Count : 1]

- startup_stm32f103xb.o(RESET)

USB_LP_CAN1_RX0_IRQHandler (Thumb, 0 bytes, Stack size 0 bytes, startup_stm32f103xb.o(.text))
[Address Reference Count : 1]

- startup_stm32f103xb.o(RESET)

WWDG_IRQHandler (Thumb, 0 bytes, Stack size 0 bytes, startup_stm32f103xb.o(.text))
[Address Reference Count : 1]

- startup_stm32f103xb.o(RESET)

__user_initial_stackheap (Thumb, 0 bytes, Stack size unknown bytes, startup_stm32f103xb.o(.text))

[Called By]

- >> __user_setup_stackheap

__aeabi_memclr4 (Thumb, 0 bytes, Stack size 4 bytes, rt_memclr_w.o(.text))

[Stack]

- Max Depth = 4
- Call Chain = __aeabi_memclr4

[Called By]

- >> SystemClock_Config
- >> MX_TIM2_Init

__aeabi_memclr8 (Thumb, 0 bytes, Stack size 4 bytes, rt_memclr_w.o(.text), UNUSED)

__rt_memclr_w (Thumb, 78 bytes, Stack size 4 bytes, rt_memclr_w.o(.text), UNUSED)

_memset_w (Thumb, 0 bytes, Stack size unknown bytes, rt_memclr_w.o(.text), UNUSED)

__use_two_region_memory (Thumb, 2 bytes, Stack size 0 bytes, heapauxi.o(.text), UNUSED)

__rt_heap_escrow$2region (Thumb, 2 bytes, Stack size 0 bytes, heapauxi.o(.text), UNUSED)

__rt_heap_expand$2region (Thumb, 2 bytes, Stack size 0 bytes, heapauxi.o(.text), UNUSED)

__user_setup_stackheap (Thumb, 74 bytes, Stack size 8 bytes, sys_stackheap_outer.o(.text))

[Stack]

- Max Depth = 8 + Unknown Stack Size
- Call Chain = __user_setup_stackheap

[Calls]

- >> __user_initial_stackheap
- >> __user_perproc_libspace

[Called By]

- >> __rt_entry_sh

exit (Thumb, 18 bytes, Stack size 8 bytes, exit.o(.text))

[Stack]

- Max Depth = 8 + Unknown Stack Size
- Call Chain = exit

[Calls]

- >> __rt_exit

[Called By]

- >> __rt_entry_main

__user_libspace (Thumb, 8 bytes, Stack size 0 bytes, libspace.o(.text), UNUSED)

__user_perproc_libspace (Thumb, 0 bytes, Stack size 0 bytes, libspace.o(.text))

[Called By]

- >> __user_setup_stackheap

__user_perthread_libspace (Thumb, 0 bytes, Stack size 0 bytes, libspace.o(.text), UNUSED)

_sys_exit (Thumb, 8 bytes, Stack size 0 bytes, sys_exit.o(.text))

[Called By]

- >> __rt_exit_exit

__I$use$semihosting (Thumb, 0 bytes, Stack size 0 bytes, use_no_semi.o(.text), UNUSED)

__use_no_semihosting_swi (Thumb, 2 bytes, Stack size 0 bytes, use_no_semi.o(.text), UNUSED)

__semihosting_library_function (Thumb, 0 bytes, Stack size unknown bytes, indicate_semi.o(.text), UNUSED)

ADC_ConversionStop_Disable (Thumb, 86 bytes, Stack size 16 bytes, stm32f1xx_hal_adc.o(i.ADC_ConversionStop_Disable))

[Stack]

- Max Depth = 16
- Call Chain = ADC_ConversionStop_Disable

[Calls]

- >> HAL_GetTick

[Called By]

- >> HAL_ADC_Stop
- >> HAL_ADC_Init

ADC_Enable (Thumb, 114 bytes, Stack size 24 bytes, stm32f1xx_hal_adc.o(i.ADC_Enable))

[Stack]

- Max Depth = 24
- Call Chain = ADC_Enable

[Calls]

- >> HAL_GetTick

[Called By]

- >> HAL_ADC_Start

ADC_Select_CH (Thumb, 30 bytes, Stack size 16 bytes, main.o(i.ADC_Select_CH))

[Stack]

- Max Depth = 40
- Call Chain = ADC_Select_CH ⇒ HAL_ADC_ConfigChannel

[Calls]

- >> HAL_ADC_ConfigChannel

[Called By]

- >> adc_scan

BusFault_Handler (Thumb, 2 bytes, Stack size 0 bytes, stm32f1xx_it.o(i.BusFault_Handler))

[Calls]

- >> BusFault_Handler

[Called By]

- >> BusFault_Handler

[Address Reference Count : 1]

- startup_stm32f103xb.o(RESET)

DebugMon_Handler (Thumb, 2 bytes, Stack size 0 bytes, stm32f1xx_it.o(i.DebugMon_Handler))
[Address Reference Count : 1]

- startup_stm32f103xb.o(RESET)

HAL_ADC_ConfigChannel (Thumb, 240 bytes, Stack size 24 bytes, stm32f1xx_hal_adc.o(i.HAL_ADC_ConfigChannel))

[Stack]

- Max Depth = 24
- Call Chain = HAL_ADC_ConfigChannel

[Called By]

- >> ADC_Select_CH
- >> MX_ADC1_Init

HAL_ADC_GetValue (Thumb, 6 bytes, Stack size 0 bytes, stm32f1xx_hal_adc.o(i.HAL_ADC_GetValue))

[Called By]

- >> adc_scan

HAL_ADC_Init (Thumb, 272 bytes, Stack size 24 bytes, stm32f1xx_hal_adc.o(i.HAL_ADC_Init))

[Stack]

- Max Depth = 88
- Call Chain = HAL_ADC_Init ⇒ HAL_ADC_MspInit ⇒ HAL_GPIO_Init

[Calls]

- >> ADC_ConversionStop_Disable
- >> HAL_ADC_MspInit

[Called By]

- >> MX_ADC1_Init

HAL_ADC_MspInit (Thumb, 76 bytes, Stack size 24 bytes, stm32f1xx_hal_msp.o(i.HAL_ADC_MspInit))

[Stack]

- Max Depth = 64
- Call Chain = HAL_ADC_MspInit ⇒ HAL_GPIO_Init

[Calls]

- >> HAL_GPIO_Init

[Called By]

- >> HAL_ADC_Init

HAL_ADC_PollForConversion (Thumb, 304 bytes, Stack size 32 bytes, stm32f1xx_hal_adc.o(i.HAL_ADC_PollForConversion))

[Stack]

- Max Depth = 64
- Call Chain = HAL_ADC_PollForConversion ⇒ HAL_RCCEx_GetPeriphCLKFreq

[Calls]

- >> HAL_RCCEx_GetPeriphCLKFreq
- >> HAL_GetTick

[Called By]

- >> adc_scan

HAL_ADC_Start (Thumb, 184 bytes, Stack size 16 bytes, stm32f1xx_hal_adc.o(i.HAL_ADC_Start))

[Stack]

- Max Depth = 40
- Call Chain = HAL_ADC_Start ⇒ ADC_Enable

[Calls]

- >> ADC_Enable

[Called By]

- >> adc_scan

HAL_ADC_Stop (Thumb, 52 bytes, Stack size 8 bytes, stm32f1xx_hal_adc.o(i.HAL_ADC_Stop))

[Stack]

- Max Depth = 24
- Call Chain = HAL_ADC_Stop ⇒ ADC_ConversionStop_Disable

[Calls]

- >> ADC_ConversionStop_Disable

[Called By]

- >> adc_scan

HAL_Delay (Thumb, 32 bytes, Stack size 16 bytes, stm32f1xx_hal.o(i.HAL_Delay))

[Stack]

- Max Depth = 16
- Call Chain = HAL_Delay

[Calls]

- >> HAL_GetTick

[Called By]

- >> OLED_Init
- >> main

HAL_GPIO_Init (Thumb, 446 bytes, Stack size 40 bytes, stm32f1xx_hal_gpio.o(i.HAL_GPIO_Init))

[Stack]

- Max Depth = 40
- Call Chain = HAL_GPIO_Init

[Called By]

- >> HAL_UART_MspInit
- >> HAL_I2C_MspInit
- >> HAL_ADC_MspInit
- >> HAL_TIM_MspPostInit
- >> MX_GPIO_Init

HAL_GPIO_TogglePin (Thumb, 16 bytes, Stack size 0 bytes, stm32f1xx_hal_gpio.o(i.HAL_GPIO_TogglePin))

[Called By]

- >> main

HAL_GPIO_WritePin (Thumb, 10 bytes, Stack size 0 bytes, stm32f1xx_hal_gpio.o(i.HAL_GPIO_WritePin))

[Called By]

- >> MX_GPIO_Init

HAL_GetTick (Thumb, 6 bytes, Stack size 0 bytes, stm32f1xx_hal.o(i.HAL_GetTick))

[Called By]

- >> ADC_Enable
- >> ADC_ConversionStop_Disable
- >> HAL_RCC_OscConfig
- >> HAL_RCC_ClockConfig
- >> HAL_RCCEx_PeriphCLKConfig
- >> HAL_IWDG_Init
- >> HAL_Delay
- >> HAL_ADC_PollForConversion
- >> HAL_I2C_Mem_Write
- >> I2C_WaitOnTXEFlagUntilTimeout
- >> I2C_WaitOnMasterAddressFlagUntilTimeout
- >> I2C_WaitOnFlagUntilTimeout
- >> I2C_WaitOnBTFFlagUntilTimeout

HAL_I2C_Init (Thumb, 376 bytes, Stack size 16 bytes, stm32f1xx_hal_i2c.o(i.HAL_I2C_Init))

[Stack]

- Max Depth = 88
- Call Chain = HAL_I2C_Init ⇒ HAL_I2C_MspInit ⇒ HAL_GPIO_Init

[Calls]

- >> HAL_I2C_MspInit
- >> HAL_RCC_GetPCLK1Freq

[Called By]

- >> main

HAL_I2C_Mem_Write (Thumb, 294 bytes, Stack size 64 bytes, stm32f1xx_hal_i2c.o(i.HAL_I2C_Mem_Write))

[Stack]

- Max Depth = 128
- Call Chain = HAL_I2C_Mem_Write ⇒ I2C_RequestMemoryWrite ⇒ I2C_WaitOnMasterAddressFlagUntilTimeout

[Calls]

- >> HAL_GetTick
- >> I2C_WaitOnTXEFlagUntilTimeout
- >> I2C_WaitOnFlagUntilTimeout
- >> I2C_WaitOnBTFFlagUntilTimeout
- >> I2C_RequestMemoryWrite

[Called By]

- >> WriteDat
- >> WriteCmd

HAL_I2C_MspInit (Thumb, 80 bytes, Stack size 32 bytes, stm32f1xx_hal_msp.o(i.HAL_I2C_MspInit))

[Stack]

- Max Depth = 72
- Call Chain = HAL_I2C_MspInit ⇒ HAL_GPIO_Init

[Calls]

- >> HAL_GPIO_Init

[Called By]

- >> HAL_I2C_Init

HAL_IWDG_Init (Thumb, 90 bytes, Stack size 16 bytes, stm32f1xx_hal_iwdg.o(i.HAL_IWDG_Init))

[Stack]

- Max Depth = 16
- Call Chain = HAL_IWDG_Init

[Calls]

- >> HAL_GetTick

[Called By]

- >> main

HAL_IWDG_Refresh (Thumb, 12 bytes, Stack size 0 bytes, stm32f1xx_hal_iwdg.o(i.HAL_IWDG_Refresh))

[Called By]

- >> main
- >> HAL_TIM_OC_DelayElapsedCallback

HAL_IncTick (Thumb, 12 bytes, Stack size 0 bytes, stm32f1xx_hal.o(i.HAL_IncTick))

[Called By]

- >> SysTick_Handler

HAL_Init (Thumb, 32 bytes, Stack size 8 bytes, stm32f1xx_hal.o(i.HAL_Init))

[Stack]

- Max Depth = 40
- Call Chain = HAL_Init ⇒ HAL_InitTick ⇒ HAL_NVIC_SetPriority

[Calls]

- >> HAL_MspInit
- >> HAL_InitTick
- >> HAL_NVIC_SetPriorityGrouping

[Called By]

- >> main

HAL_InitTick (Thumb, 54 bytes, Stack size 16 bytes, stm32f1xx_hal.o(i.HAL_InitTick))

[Stack]

- Max Depth = 32
- Call Chain = HAL_InitTick ⇒ HAL_NVIC_SetPriority

[Calls]

- >> HAL_NVIC_SetPriority
- >> HAL_SYSTICK_Config

[Called By]

- >> HAL_RCC_ClockConfig
- >> HAL_Init

HAL_MspInit (Thumb, 52 bytes, Stack size 8 bytes, stm32f1xx_hal_msp.o(i.HAL_MspInit))

[Stack]

- Max Depth = 8
- Call Chain = HAL_MspInit

[Called By]

- >> HAL_Init

HAL_NVIC_EnableIRQ (Thumb, 26 bytes, Stack size 0 bytes, stm32f1xx_hal_cortex.o(i.HAL_NVIC_EnableIRQ))

[Called By]

- >> HAL_TIM_Base_MspInit

HAL_NVIC_SetPriority (Thumb, 60 bytes, Stack size 16 bytes, stm32f1xx_hal_cortex.o(i.HAL_NVIC_SetPriority))

[Stack]

- Max Depth = 16
- Call Chain = HAL_NVIC_SetPriority

[Calls]

- >> __NVIC_SetPriority

[Called By]

- >> HAL_TIM_Base_MspInit
- >> HAL_InitTick

HAL_NVIC_SetPriorityGrouping (Thumb, 26 bytes, Stack size 0 bytes, stm32f1xx_hal_cortex.o(i.HAL_NVIC_SetPriorityGrouping))

[Called By]

- >> HAL_Init

HAL_RCCEx_GetPeriphCLKFreq (Thumb, 166 bytes, Stack size 32 bytes, stm32f1xx_hal_rcc_ex.o(i.HAL_RCCEx_GetPeriphCLKFreq))

[Stack]

- Max Depth = 32
- Call Chain = HAL_RCCEx_GetPeriphCLKFreq

[Calls]

- >> HAL_RCC_GetPCLK2Freq

[Called By]

- >> HAL_ADC_PollForConversion

HAL_RCCEx_PeriphCLKConfig (Thumb, 224 bytes, Stack size 32 bytes, stm32f1xx_hal_rcc_ex.o(i.HAL_RCCEx_PeriphCLKConfig))

[Stack]

- Max Depth = 32
- Call Chain = HAL_RCCEx_PeriphCLKConfig

[Calls]

- >> HAL_GetTick

[Called By]

- >> SystemClock_Config

HAL_RCC_ClockConfig (Thumb, 280 bytes, Stack size 32 bytes, stm32f1xx_hal_rcc.o(i.HAL_RCC_ClockConfig))

[Stack]

- Max Depth = 64
- Call Chain = HAL_RCC_ClockConfig ⇒ HAL_InitTick ⇒ HAL_NVIC_SetPriority

[Calls]

- >> HAL_GetTick
- >> HAL_RCC_GetSysClockFreq
- >> HAL_InitTick

[Called By]

- >> SystemClock_Config

HAL_RCC_GetPCLK1Freq (Thumb, 20 bytes, Stack size 0 bytes, stm32f1xx_hal_rcc.o(i.HAL_RCC_GetPCLK1Freq))

[Called By]

- >> HAL_I2C_Init
- >> UART_SetConfig

HAL_RCC_GetPCLK2Freq (Thumb, 20 bytes, Stack size 0 bytes, stm32f1xx_hal_rcc.o(i.HAL_RCC_GetPCLK2Freq))

[Called By]

- >> HAL_RCCEx_GetPeriphCLKFreq
- >> UART_SetConfig

HAL_RCC_GetSysClockFreq (Thumb, 74 bytes, Stack size 20 bytes, stm32f1xx_hal_rcc.o(i.HAL_RCC_GetSysClockFreq))

[Stack]

- Max Depth = 20
- Call Chain = HAL_RCC_GetSysClockFreq

[Called By]

- >> HAL_RCC_ClockConfig

HAL_RCC_OscConfig (Thumb, 778 bytes, Stack size 40 bytes, stm32f1xx_hal_rcc.o(i.HAL_RCC_OscConfig))

[Stack]

- Max Depth = 40
- Call Chain = HAL_RCC_OscConfig

[Calls]

- >> HAL_GetTick

[Called By]

- >> SystemClock_Config

HAL_SYSTICK_Config (Thumb, 40 bytes, Stack size 8 bytes, stm32f1xx_hal_cortex.o(i.HAL_SYSTICK_Config))

[Stack]

- Max Depth = 8
- Call Chain = HAL_SYSTICK_Config

[Calls]

- >> __NVIC_SetPriority

[Called By]

- >> HAL_InitTick

HAL_TIMEx_BreakCallback (Thumb, 2 bytes, Stack size 0 bytes, stm32f1xx_hal_tim_ex.o(i.HAL_TIMEx_BreakCallback))

[Called By]

- >> HAL_TIM_IRQHandler

HAL_TIMEx_CommutCallback (Thumb, 2 bytes, Stack size 0 bytes, stm32f1xx_hal_tim_ex.o(i.HAL_TIMEx_CommutCallback))

[Called By]

- >> HAL_TIM_IRQHandler

HAL_TIMEx_MasterConfigSynchronization (Thumb, 92 bytes, Stack size 16 bytes, stm32f1xx_hal_tim_ex.o(i.HAL_TIMEx_MasterConfigSynchronization))

[Stack]

- Max Depth = 16
- Call Chain = HAL_TIMEx_MasterConfigSynchronization

[Called By]

- >> MX_TIM2_Init

HAL_TIM_Base_Init (Thumb, 90 bytes, Stack size 8 bytes, stm32f1xx_hal_tim.o(i.HAL_TIM_Base_Init))

[Stack]

- Max Depth = 32
- Call Chain = HAL_TIM_Base_Init ⇒ HAL_TIM_Base_MspInit ⇒ HAL_NVIC_SetPriority

[Calls]

- >> HAL_TIM_Base_MspInit
- >> TIM_Base_SetConfig

[Called By]

- >> MX_TIM2_Init

HAL_TIM_Base_MspInit (Thumb, 50 bytes, Stack size 8 bytes, stm32f1xx_hal_msp.o(i.HAL_TIM_Base_MspInit))

[Stack]

- Max Depth = 24
- Call Chain = HAL_TIM_Base_MspInit ⇒ HAL_NVIC_SetPriority

[Calls]

- >> HAL_NVIC_SetPriority
- >> HAL_NVIC_EnableIRQ

[Called By]

- >> HAL_TIM_Base_Init

HAL_TIM_Base_Start_IT (Thumb, 76 bytes, Stack size 0 bytes, stm32f1xx_hal_tim.o(i.HAL_TIM_Base_Start_IT))

[Called By]

- >> main

HAL_TIM_ConfigClockSource (Thumb, 214 bytes, Stack size 16 bytes, stm32f1xx_hal_tim.o(i.HAL_TIM_ConfigClockSource))

[Stack]

- Max Depth = 24
- Call Chain = HAL_TIM_ConfigClockSource ⇒ TIM_TI2_ConfigInputStage

[Calls]

- >> TIM_TI2_ConfigInputStage
- >> TIM_TI1_ConfigInputStage
- >> TIM_ITRx_SetConfig
- >> TIM_ETR_SetConfig

[Called By]

- >> MX_TIM2_Init

HAL_TIM_IC_CaptureCallback (Thumb, 2 bytes, Stack size 0 bytes, stm32f1xx_hal_tim.o(i.HAL_TIM_IC_CaptureCallback))

[Called By]

- >> HAL_TIM_IRQHandler

HAL_TIM_IRQHandler (Thumb, 358 bytes, Stack size 16 bytes, stm32f1xx_hal_tim.o(i.HAL_TIM_IRQHandler))

[Stack]

- Max Depth = 152
- Call Chain = HAL_TIM_IRQHandler ⇒ HAL_TIM_OC_DelayElapsedCallback ⇒ adc_scan ⇒ HAL_ADC_PollForConversion ⇒ HAL_RCCEx_GetPeriphCLKFreq

[Calls]

- >> HAL_TIM_OC_DelayElapsedCallback
- >> HAL_TIM_TriggerCallback
- >> HAL_TIM_PeriodElapsedCallback
- >> HAL_TIM_PWM_PulseFinishedCallback
- >> HAL_TIM_IC_CaptureCallback
- >> HAL_TIMEx_CommutCallback
- >> HAL_TIMEx_BreakCallback

[Called By]

- >> TIM2_IRQHandler

HAL_TIM_MspPostInit (Thumb, 62 bytes, Stack size 24 bytes, stm32f1xx_hal_msp.o(i.HAL_TIM_MspPostInit))

[Stack]

- Max Depth = 64
- Call Chain = HAL_TIM_MspPostInit ⇒ HAL_GPIO_Init

[Calls]

- >> HAL_GPIO_Init

[Called By]

- >> MX_TIM2_Init

HAL_TIM_OC_ConfigChannel (Thumb, 76 bytes, Stack size 8 bytes, stm32f1xx_hal_tim.o(i.HAL_TIM_OC_ConfigChannel))

[Stack]

- Max Depth = 20
- Call Chain = HAL_TIM_OC_ConfigChannel ⇒ TIM_OC4_SetConfig

[Calls]

- >> TIM_OC4_SetConfig
- >> TIM_OC3_SetConfig
- >> TIM_OC1_SetConfig
- >> TIM_OC2_SetConfig

[Called By]

- >> MX_TIM2_Init

HAL_TIM_OC_DelayElapsedCallback (Thumb, 276 bytes, Stack size 32 bytes, main.o(i.HAL_TIM_OC_DelayElapsedCallback))

[Stack]

- Max Depth = 136
- Call Chain = HAL_TIM_OC_DelayElapsedCallback ⇒ adc_scan ⇒ HAL_ADC_PollForConversion ⇒ HAL_RCCEx_GetPeriphCLKFreq

[Calls]

- >> HAL_IWDG_Refresh
- >> adc_scan
- >> __ARM_scalbnf
- >> __aeabi_fmul
- >> __aeabi_ui2f
- >> __aeabi_i2f
- >> __aeabi_f2iz
- >> __aeabi_fsub
- >> __aeabi_fadd
- >> __aeabi_dmul
- >> __aeabi_ui2d
- >> __aeabi_d2iz
- >> __aeabi_dadd

[Called By]

- >> HAL_TIM_IRQHandler

HAL_TIM_OC_Init (Thumb, 90 bytes, Stack size 8 bytes, stm32f1xx_hal_tim.o(i.HAL_TIM_OC_Init))

[Stack]

- Max Depth = 28
- Call Chain = HAL_TIM_OC_Init ⇒ TIM_Base_SetConfig

[Calls]

- >> HAL_TIM_OC_MspInit
- >> TIM_Base_SetConfig

[Called By]

- >> MX_TIM2_Init

HAL_TIM_OC_MspInit (Thumb, 2 bytes, Stack size 0 bytes, stm32f1xx_hal_tim.o(i.HAL_TIM_OC_MspInit))

[Called By]

- >> HAL_TIM_OC_Init

HAL_TIM_OC_Start_IT (Thumb, 184 bytes, Stack size 8 bytes, stm32f1xx_hal_tim.o(i.HAL_TIM_OC_Start_IT))

[Stack]

- Max Depth = 16
- Call Chain = HAL_TIM_OC_Start_IT ⇒ TIM_CCxChannelCmd

[Calls]

- >> TIM_CCxChannelCmd

[Called By]

- >> main

HAL_TIM_PWM_ConfigChannel (Thumb, 198 bytes, Stack size 16 bytes, stm32f1xx_hal_tim.o(i.HAL_TIM_PWM_ConfigChannel))

[Stack]

- Max Depth = 28
- Call Chain = HAL_TIM_PWM_ConfigChannel ⇒ TIM_OC4_SetConfig

[Calls]

- >> TIM_OC4_SetConfig
- >> TIM_OC3_SetConfig
- >> TIM_OC1_SetConfig
- >> TIM_OC2_SetConfig

[Called By]

- >> MX_TIM2_Init

HAL_TIM_PWM_Init (Thumb, 90 bytes, Stack size 8 bytes, stm32f1xx_hal_tim.o(i.HAL_TIM_PWM_Init))

[Stack]

- Max Depth = 28
- Call Chain = HAL_TIM_PWM_Init ⇒ TIM_Base_SetConfig

[Calls]

- >> HAL_TIM_PWM_MspInit
- >> TIM_Base_SetConfig

[Called By]

- >> MX_TIM2_Init

HAL_TIM_PWM_MspInit (Thumb, 2 bytes, Stack size 0 bytes, stm32f1xx_hal_tim.o(i.HAL_TIM_PWM_MspInit))

[Called By]

- >> HAL_TIM_PWM_Init

HAL_TIM_PWM_PulseFinishedCallback (Thumb, 2 bytes, Stack size 0 bytes, stm32f1xx_hal_tim.o(i.HAL_TIM_PWM_PulseFinishedCallback))

[Called By]

- >> HAL_TIM_IRQHandler

HAL_TIM_PWM_Start (Thumb, 144 bytes, Stack size 8 bytes, stm32f1xx_hal_tim.o(i.HAL_TIM_PWM_Start))

[Stack]

- Max Depth = 16
- Call Chain = HAL_TIM_PWM_Start ⇒ TIM_CCxChannelCmd

[Calls]

- >> TIM_CCxChannelCmd

[Called By]

- >> main

HAL_TIM_PeriodElapsedCallback (Thumb, 2 bytes, Stack size 0 bytes, stm32f1xx_hal_tim.o(i.HAL_TIM_PeriodElapsedCallback))

[Called By]

- >> HAL_TIM_IRQHandler

HAL_TIM_TriggerCallback (Thumb, 2 bytes, Stack size 0 bytes, stm32f1xx_hal_tim.o(i.HAL_TIM_TriggerCallback))

[Called By]

- >> HAL_TIM_IRQHandler

HAL_UART_Init (Thumb, 98 bytes, Stack size 16 bytes, stm32f1xx_hal_uart.o(i.HAL_UART_Init))

[Stack]

- Max Depth = 88
- Call Chain = HAL_UART_Init ⇒ HAL_UART_MspInit ⇒ HAL_GPIO_Init

[Calls]

- >> HAL_UART_MspInit
- >> UART_SetConfig

[Called By]

- >> main

HAL_UART_MspInit (Thumb, 100 bytes, Stack size 32 bytes, stm32f1xx_hal_msp.o(i.HAL_UART_MspInit))

[Stack]

- Max Depth = 72
- Call Chain = HAL_UART_MspInit ⇒ HAL_GPIO_Init

[Calls]

- >> HAL_GPIO_Init

[Called By]

- >> HAL_UART_Init

HardFault_Handler (Thumb, 2 bytes, Stack size 0 bytes, stm32f1xx_it.o(i.HardFault_Handler))

[Calls]

- >> HardFault_Handler

[Called By]

- >> HardFault_Handler

[Address Reference Count : 1]

- startup_stm32f103xb.o(RESET)

MemManage_Handler (Thumb, 2 bytes, Stack size 0 bytes, stm32f1xx_it.o(i.MemManage_Handler))

[Calls]

- >> MemManage_Handler

[Called By]

- >> MemManage_Handler

[Address Reference Count : 1]

- startup_stm32f103xb.o(RESET)

NMI_Handler (Thumb, 2 bytes, Stack size 0 bytes, stm32f1xx_it.o(i.NMI_Handler))

[Calls]

- >> NMI_Handler

[Called By]

- >> NMI_Handler

[Address Reference Count : 1]

- startup_stm32f103xb.o(RESET)

OLED_CLS (Thumb, 6 bytes, Stack size 0 bytes, oled.o(i.OLED_CLS))

[Stack]

- Max Depth = 168
- Call Chain = OLED_CLS ⇒ OLED_Fill ⇒ WriteDat ⇒ HAL_I2C_Mem_Write ⇒ I2C_RequestMemoryWrite ⇒ I2C_WaitOnMasterAddressFlagUntilTimeout

[Calls]

- >> OLED_Fill

[Called By]

- >> main

OLED_Fill (Thumb, 56 bytes, Stack size 16 bytes, oled.o(i.OLED_Fill))

[Stack]

- Max Depth = 168
- Call Chain = OLED_Fill ⇒ WriteDat ⇒ HAL_I2C_Mem_Write ⇒ I2C_RequestMemoryWrite ⇒ I2C_WaitOnMasterAddressFlagUntilTimeout

[Calls]

- >> WriteDat
- >> WriteCmd

[Called By]

- >> OLED_CLS

OLED_Init (Thumb, 180 bytes, Stack size 8 bytes, oled.o(i.OLED_Init))

[Stack]

- Max Depth = 160
- Call Chain = OLED_Init ⇒ WriteCmd ⇒ HAL_I2C_Mem_Write ⇒ I2C_RequestMemoryWrite ⇒ I2C_WaitOnMasterAddressFlagUntilTimeout

[Calls]

- >> HAL_Delay
- >> WriteCmd

[Called By]

- >> main

OLED_SetPos (Thumb, 38 bytes, Stack size 8 bytes, oled.o(i.OLED_SetPos))

[Stack]

- Max Depth = 160
- Call Chain = OLED_SetPos ⇒ WriteCmd ⇒ HAL_I2C_Mem_Write ⇒ I2C_RequestMemoryWrite ⇒ I2C_WaitOnMasterAddressFlagUntilTimeout

[Calls]

- >> WriteCmd

[Called By]

- >> OLED_ShowCN

OLED_ShowCN (Thumb, 70 bytes, Stack size 32 bytes, oled.o(i.OLED_ShowCN))

[Stack]

- Max Depth = 192
- Call Chain = OLED_ShowCN ⇒ OLED_SetPos ⇒ WriteCmd ⇒ HAL_I2C_Mem_Write ⇒ I2C_RequestMemoryWrite ⇒ I2C_WaitOnMasterAddressFlagUntilTimeout

[Calls]

- >> WriteDat
- >> OLED_SetPos

[Called By]

- >> oled_show

PendSV_Handler (Thumb, 2 bytes, Stack size 0 bytes, stm32f1xx_it.o(i.PendSV_Handler))
[Address Reference Count : 1]

- startup_stm32f103xb.o(RESET)

SVC_Handler (Thumb, 2 bytes, Stack size 0 bytes, stm32f1xx_it.o(i.SVC_Handler))
[Address Reference Count : 1]

- startup_stm32f103xb.o(RESET)

SysTick_Handler (Thumb, 4 bytes, Stack size 0 bytes, stm32f1xx_it.o(i.SysTick_Handler))

[Calls]

- >> HAL_IncTick

[Address Reference Count : 1]

- startup_stm32f103xb.o(RESET)

SystemClock_Config (Thumb, 128 bytes, Stack size 88 bytes, main.o(i.SystemClock_Config))

[Stack]

- Max Depth = 152
- Call Chain = SystemClock_Config ⇒ HAL_RCC_ClockConfig ⇒ HAL_InitTick ⇒ HAL_NVIC_SetPriority

[Calls]

- >> HAL_RCC_OscConfig
- >> HAL_RCC_ClockConfig
- >> HAL_RCCEx_PeriphCLKConfig
- >> __aeabi_memclr4

[Called By]

- >> main

SystemInit (Thumb, 2 bytes, Stack size 0 bytes, system_stm32f1xx.o(i.SystemInit))
[Address Reference Count : 1]

- startup_stm32f103xb.o(.text)

TIM2_IRQHandler (Thumb, 6 bytes, Stack size 0 bytes, stm32f1xx_it.o(i.TIM2_IRQHandler))

[Stack]

- Max Depth = 152
- Call Chain = TIM2_IRQHandler ⇒ HAL_TIM_IRQHandler ⇒ HAL_TIM_OC_DelayElapsedCallback ⇒ adc_scan ⇒ HAL_ADC_PollForConversion ⇒ HAL_RCCEx_GetPeriphCLKFreq

[Calls]

- >> HAL_TIM_IRQHandler

[Address Reference Count : 1]

- startup_stm32f103xb.o(RESET)

TIM_Base_SetConfig (Thumb, 94 bytes, Stack size 20 bytes, stm32f1xx_hal_tim.o(i.TIM_Base_SetConfig))

[Stack]

- Max Depth = 20
- Call Chain = TIM_Base_SetConfig

[Called By]

- >> HAL_TIM_PWM_Init
- >> HAL_TIM_OC_Init
- >> HAL_TIM_Base_Init

TIM_CCxChannelCmd (Thumb, 26 bytes, Stack size 8 bytes, stm32f1xx_hal_tim.o(i.TIM_CCxChannelCmd))

[Stack]

- Max Depth = 8
- Call Chain = TIM_CCxChannelCmd

[Called By]

- >> HAL_TIM_PWM_Start
- >> HAL_TIM_OC_Start_IT

TIM_ETR_SetConfig (Thumb, 20 bytes, Stack size 8 bytes, stm32f1xx_hal_tim.o(i.TIM_ETR_SetConfig))

[Stack]

- Max Depth = 8
- Call Chain = TIM_ETR_SetConfig

[Called By]

- >> HAL_TIM_ConfigClockSource

TIM_OC2_SetConfig (Thumb, 84 bytes, Stack size 12 bytes, stm32f1xx_hal_tim.o(i.TIM_OC2_SetConfig))

[Stack]

- Max Depth = 12
- Call Chain = TIM_OC2_SetConfig

[Called By]

- >> HAL_TIM_PWM_ConfigChannel
- >> HAL_TIM_OC_ConfigChannel

UsageFault_Handler (Thumb, 2 bytes, Stack size 0 bytes, stm32f1xx_it.o(i.UsageFault_Handler))

[Calls]

- >> UsageFault_Handler

[Called By]

- >> UsageFault_Handler

[Address Reference Count : 1]

- startup_stm32f103xb.o(RESET)

WriteCmd (Thumb, 30 bytes, Stack size 24 bytes, oled.o(i.WriteCmd))

[Stack]

- Max Depth = 152
- Call Chain = WriteCmd ⇒ HAL_I2C_Mem_Write ⇒ I2C_RequestMemoryWrite ⇒ I2C_WaitOnMasterAddressFlagUntilTimeout

[Calls]

- >> HAL_I2C_Mem_Write

[Called By]

- >> OLED_Init
- >> OLED_SetPos
- >> OLED_Fill

WriteDat (Thumb, 30 bytes, Stack size 24 bytes, oled.o(i.WriteDat))

[Stack]

- Max Depth = 152
- Call Chain = WriteDat ⇒ HAL_I2C_Mem_Write ⇒ I2C_RequestMemoryWrite ⇒ I2C_WaitOnMasterAddressFlagUntilTimeout

[Calls]

- >> HAL_I2C_Mem_Write

[Called By]

- >> OLED_ShowCN
- >> OLED_Fill

adc_scan (Thumb, 230 bytes, Stack size 40 bytes, main.o(i.adc_scan))

[Stack]

- Max Depth = 104
- Call Chain = adc_scan ⇒ HAL_ADC_PollForConversion ⇒ HAL_RCCEx_GetPeriphCLKFreq

[Calls]

- >> HAL_ADC_Stop
- >> HAL_ADC_Start
- >> HAL_ADC_PollForConversion
- >> HAL_ADC_GetValue
- >> ADC_Select_CH
- >> __aeabi_dmul
- >> __aeabi_ui2d
- >> __aeabi_d2uiz
- >> __aeabi_dadd

[Called By]

- >> HAL_TIM_OC_DelayElapsedCallback

main (Thumb, 200 bytes, Stack size 0 bytes, main.o(i.main))

[Stack]

- Max Depth = 216
- Call Chain = main ⇒ oled_show ⇒ OLED_ShowCN ⇒ OLED_SetPos ⇒ WriteCmd ⇒ HAL_I2C_Mem_Write ⇒ I2C_RequestMemoryWrite ⇒ I2C_WaitOnMasterAddressFlagUntilTimeout

[Calls]

- >> OLED_Init
- >> OLED_CLS
- >> HAL_UART_Init
- >> HAL_TIM_PWM_Start
- >> HAL_TIM_OC_Start_IT
- >> HAL_TIM_Base_Start_IT
- >> HAL_Init
- >> HAL_IWDG_Refresh
- >> HAL_IWDG_Init
- >> HAL_I2C_Init
- >> HAL_GPIO_TogglePin
- >> HAL_Delay
- >> oled_show
- >> SystemClock_Config
- >> MX_TIM2_Init
- >> MX_GPIO_Init
- >> MX_ADC1_Init

[Called By]

- >> __rt_entry_main

oled_show (Thumb, 230 bytes, Stack size 24 bytes, main.o(i.oled_show))

[Stack]

- Max Depth = 216
- Call Chain = oled_show ⇒ OLED_ShowCN ⇒ OLED_SetPos ⇒ WriteCmd ⇒ HAL_I2C_Mem_Write ⇒ I2C_RequestMemoryWrite ⇒ I2C_WaitOnMasterAddressFlagUntilTimeout

[Calls]

- >> OLED_ShowCN

[Called By]

- >> main

__aeabi_dadd (Thumb, 0 bytes, Stack size 16 bytes, daddsub_clz.o(x$fpl$dadd))

[Stack]

- Max Depth = 16
- Call Chain = __aeabi_dadd

[Called By]

- >> adc_scan
- >> HAL_TIM_OC_DelayElapsedCallback

_dadd (Thumb, 332 bytes, Stack size 16 bytes, daddsub_clz.o(x$fpl$dadd), UNUSED)

[Calls]

- >> __fpl_dretinf
- >> __fpl_dnaninf
- >> _dsub1

__aeabi_d2iz (Thumb, 0 bytes, Stack size 32 bytes, dfix.o(x$fpl$dfix))

[Stack]

- Max Depth = 32
- Call Chain = __aeabi_d2iz

[Called By]

- >> HAL_TIM_OC_DelayElapsedCallback

_dfix (Thumb, 94 bytes, Stack size 32 bytes, dfix.o(x$fpl$dfix), UNUSED)

[Calls]

- >> __fpl_dnaninf

__aeabi_d2uiz (Thumb, 0 bytes, Stack size 32 bytes, dfixu.o(x$fpl$dfixu))

[Stack]

- Max Depth = 32
- Call Chain = __aeabi_d2uiz

[Called By]

- >> adc_scan

_dfixu (Thumb, 90 bytes, Stack size 32 bytes, dfixu.o(x$fpl$dfixu), UNUSED)

[Calls]

- >> __fpl_dnaninf

__aeabi_ui2d (Thumb, 0 bytes, Stack size 0 bytes, dflt_clz.o(x$fpl$dfltu))

[Called By]

- >> adc_scan
- >> HAL_TIM_OC_DelayElapsedCallback

_dfltu (Thumb, 38 bytes, Stack size 0 bytes, dflt_clz.o(x$fpl$dfltu), UNUSED)

__aeabi_dmul (Thumb, 0 bytes, Stack size 32 bytes, dmul.o(x$fpl$dmul))

[Stack]

- Max Depth = 32
- Call Chain = __aeabi_dmul

[Called By]

- >> adc_scan
- >> HAL_TIM_OC_DelayElapsedCallback

_dmul (Thumb, 332 bytes, Stack size 32 bytes, dmul.o(x$fpl$dmul), UNUSED)

[Calls]

- >> __fpl_dretinf
- >> __fpl_dnaninf

__fpl_dnaninf (Thumb, 156 bytes, Stack size 16 bytes, dnaninf.o(x$fpl$dnaninf), UNUSED)

[Called By]

- >> _dmul
- >> _dfixu
- >> _dfix
- >> _dsub
- >> _dadd

__fpl_dretinf (Thumb, 12 bytes, Stack size 0 bytes, dretinf.o(x$fpl$dretinf), UNUSED)

[Called By]

- >> _dmul
- >> _dadd

__aeabi_dsub (Thumb, 0 bytes, Stack size 32 bytes, daddsub_clz.o(x$fpl$dsub), UNUSED)

_dsub (Thumb, 464 bytes, Stack size 32 bytes, daddsub_clz.o(x$fpl$dsub), UNUSED)

[Calls]

- >> __fpl_dnaninf
- >> _dadd1

__aeabi_fadd (Thumb, 0 bytes, Stack size 16 bytes, faddsub_clz.o(x$fpl$fadd))

[Stack]

- Max Depth = 16
- Call Chain = __aeabi_fadd

[Called By]

- >> HAL_TIM_OC_DelayElapsedCallback

_fadd (Thumb, 196 bytes, Stack size 16 bytes, faddsub_clz.o(x$fpl$fadd), UNUSED)

[Calls]

- >> __fpl_fretinf
- >> __fpl_fnaninf
- >> _fsub1

__fpl_fcheck_NaN1 (Thumb, 6 bytes, Stack size 0 bytes, fcheck1.o(x$fpl$fcheck1))

[Calls]

- >> __fpl_return_NaN

[Called By]

- >> __ARM_scalbnf

__aeabi_f2iz (Thumb, 0 bytes, Stack size 16 bytes, ffix.o(x$fpl$ffix))

[Stack]

- Max Depth = 16
- Call Chain = __aeabi_f2iz

[Called By]

- >> HAL_TIM_OC_DelayElapsedCallback

_ffix (Thumb, 54 bytes, Stack size 16 bytes, ffix.o(x$fpl$ffix), UNUSED)

[Calls]

- >> __fpl_fnaninf

__aeabi_i2f (Thumb, 0 bytes, Stack size 0 bytes, fflt_clz.o(x$fpl$fflt))

[Called By]

- >> HAL_TIM_OC_DelayElapsedCallback

_fflt (Thumb, 48 bytes, Stack size 0 bytes, fflt_clz.o(x$fpl$fflt), UNUSED)

__aeabi_ui2f (Thumb, 0 bytes, Stack size 0 bytes, fflt_clz.o(x$fpl$ffltu))

[Called By]

- >> HAL_TIM_OC_DelayElapsedCallback

_ffltu (Thumb, 38 bytes, Stack size 0 bytes, fflt_clz.o(x$fpl$ffltu), UNUSED)

__aeabi_fmul (Thumb, 0 bytes, Stack size 16 bytes, fmul.o(x$fpl$fmul))

[Stack]

- Max Depth = 16
- Call Chain = __aeabi_fmul

[Called By]

- >> HAL_TIM_OC_DelayElapsedCallback

_fmul (Thumb, 258 bytes, Stack size 16 bytes, fmul.o(x$fpl$fmul), UNUSED)

[Calls]

- >> __fpl_fretinf
- >> __fpl_fnaninf

__fpl_fnaninf (Thumb, 140 bytes, Stack size 8 bytes, fnaninf.o(x$fpl$fnaninf), UNUSED)

[Called By]

- >> _fmul
- >> _ffix
- >> _fsub
- >> _fadd

__fpl_fretinf (Thumb, 10 bytes, Stack size 0 bytes, fretinf.o(x$fpl$fretinf), UNUSED)

[Called By]

- >> _fmul
- >> _fadd

__aeabi_fsub (Thumb, 0 bytes, Stack size 16 bytes, faddsub_clz.o(x$fpl$fsub))

[Stack]

- Max Depth = 16
- Call Chain = __aeabi_fsub

[Called By]

- >> HAL_TIM_OC_DelayElapsedCallback

_fsub (Thumb, 234 bytes, Stack size 16 bytes, faddsub_clz.o(x$fpl$fsub), UNUSED)

[Calls]

- >> __fpl_fnaninf
- >> _fadd1

__fpl_return_NaN (Thumb, 100 bytes, Stack size 0 bytes, retnan.o(x$fpl$retnan))

[Calls]

- >> __fpl_cmpreturn

[Called By]

- >> __fpl_fcheck_NaN1

__ARM_scalbnf (Thumb, 76 bytes, Stack size 0 bytes, scalbnf.o(x$fpl$scalbnf))

[Calls]

- >> __fpl_fcheck_NaN1

[Called By]

- >> HAL_TIM_OC_DelayElapsedCallback

__fpl_cmpreturn (Thumb, 48 bytes, Stack size 0 bytes, trapv.o(x$fpl$trapveneer))

[Called By]

- >> __fpl_return_NaN

### Local Symbols

MX_ADC1_Init (Thumb, 68 bytes, Stack size 24 bytes, main.o(i.MX_ADC1_Init))

[Stack]

- Max Depth = 112
- Call Chain = MX_ADC1_Init ⇒ HAL_ADC_Init ⇒ HAL_ADC_MspInit ⇒ HAL_GPIO_Init

[Calls]

- >> HAL_ADC_Init
- >> HAL_ADC_ConfigChannel

[Called By]

- >> main

MX_GPIO_Init (Thumb, 120 bytes, Stack size 40 bytes, main.o(i.MX_GPIO_Init))

[Stack]

- Max Depth = 80
- Call Chain = MX_GPIO_Init ⇒ HAL_GPIO_Init

[Calls]

- >> HAL_GPIO_WritePin
- >> HAL_GPIO_Init

[Called By]

- >> main

MX_TIM2_Init (Thumb, 190 bytes, Stack size 64 bytes, main.o(i.MX_TIM2_Init))

[Stack]

- Max Depth = 128
- Call Chain = MX_TIM2_Init ⇒ HAL_TIM_MspPostInit ⇒ HAL_GPIO_Init

[Calls]

- >> HAL_TIM_PWM_Init
- >> HAL_TIM_PWM_ConfigChannel
- >> HAL_TIM_OC_Init
- >> HAL_TIM_OC_ConfigChannel
- >> HAL_TIM_MspPostInit
- >> HAL_TIM_ConfigClockSource
- >> HAL_TIM_Base_Init
- >> HAL_TIMEx_MasterConfigSynchronization
- >> __aeabi_memclr4

[Called By]

- >> main

__NVIC_SetPriority (Thumb, 32 bytes, Stack size 0 bytes, stm32f1xx_hal_cortex.o(i.__NVIC_SetPriority))

[Called By]

- >> HAL_NVIC_SetPriority
- >> HAL_SYSTICK_Config

I2C_IsAcknowledgeFailed (Thumb, 46 bytes, Stack size 0 bytes, stm32f1xx_hal_i2c.o(i.I2C_IsAcknowledgeFailed))

[Called By]

- >> I2C_WaitOnTXEFlagUntilTimeout
- >> I2C_WaitOnBTFFlagUntilTimeout

I2C_RequestMemoryWrite (Thumb, 162 bytes, Stack size 32 bytes, stm32f1xx_hal_i2c.o(i.I2C_RequestMemoryWrite))

[Stack]

- Max Depth = 64
- Call Chain = I2C_RequestMemoryWrite ⇒ I2C_WaitOnMasterAddressFlagUntilTimeout

[Calls]

- >> I2C_WaitOnTXEFlagUntilTimeout
- >> I2C_WaitOnMasterAddressFlagUntilTimeout
- >> I2C_WaitOnFlagUntilTimeout

[Called By]

- >> HAL_I2C_Mem_Write

I2C_WaitOnBTFFlagUntilTimeout (Thumb, 76 bytes, Stack size 16 bytes, stm32f1xx_hal_i2c.o(i.I2C_WaitOnBTFFlagUntilTimeout))

[Stack]

- Max Depth = 16
- Call Chain = I2C_WaitOnBTFFlagUntilTimeout

[Calls]

- >> HAL_GetTick
- >> I2C_IsAcknowledgeFailed

[Called By]

- >> HAL_I2C_Mem_Write

I2C_WaitOnFlagUntilTimeout (Thumb, 104 bytes, Stack size 32 bytes, stm32f1xx_hal_i2c.o(i.I2C_WaitOnFlagUntilTimeout))

[Stack]

- Max Depth = 32
- Call Chain = I2C_WaitOnFlagUntilTimeout

[Calls]

- >> HAL_GetTick

[Called By]

- >> HAL_I2C_Mem_Write
- >> I2C_RequestMemoryWrite

I2C_WaitOnMasterAddressFlagUntilTimeout (Thumb, 150 bytes, Stack size 32 bytes, stm32f1xx_hal_i2c.o(i.I2C_WaitOnMasterAddressFlagUntilTimeout))

[Stack]

- Max Depth = 32
- Call Chain = I2C_WaitOnMasterAddressFlagUntilTimeout

[Calls]

- >> HAL_GetTick

[Called By]

- >> I2C_RequestMemoryWrite

I2C_WaitOnTXEFlagUntilTimeout (Thumb, 76 bytes, Stack size 16 bytes, stm32f1xx_hal_i2c.o(i.I2C_WaitOnTXEFlagUntilTimeout))

[Stack]

- Max Depth = 16
- Call Chain = I2C_WaitOnTXEFlagUntilTimeout

[Calls]

- >> HAL_GetTick
- >> I2C_IsAcknowledgeFailed

[Called By]

- >> HAL_I2C_Mem_Write
- >> I2C_RequestMemoryWrite

TIM_ITRx_SetConfig (Thumb, 16 bytes, Stack size 0 bytes, stm32f1xx_hal_tim.o(i.TIM_ITRx_SetConfig))

[Called By]

- >> HAL_TIM_ConfigClockSource

TIM_OC1_SetConfig (Thumb, 74 bytes, Stack size 12 bytes, stm32f1xx_hal_tim.o(i.TIM_OC1_SetConfig))

[Stack]

- Max Depth = 12
- Call Chain = TIM_OC1_SetConfig

[Called By]

- >> HAL_TIM_PWM_ConfigChannel
- >> HAL_TIM_OC_ConfigChannel

TIM_OC3_SetConfig (Thumb, 82 bytes, Stack size 12 bytes, stm32f1xx_hal_tim.o(i.TIM_OC3_SetConfig))

[Stack]

- Max Depth = 12
- Call Chain = TIM_OC3_SetConfig

[Called By]

- >> HAL_TIM_PWM_ConfigChannel
- >> HAL_TIM_OC_ConfigChannel

TIM_OC4_SetConfig (Thumb, 64 bytes, Stack size 12 bytes, stm32f1xx_hal_tim.o(i.TIM_OC4_SetConfig))

[Stack]

- Max Depth = 12
- Call Chain = TIM_OC4_SetConfig

[Called By]

- >> HAL_TIM_PWM_ConfigChannel
- >> HAL_TIM_OC_ConfigChannel

TIM_TI1_ConfigInputStage (Thumb, 34 bytes, Stack size 8 bytes, stm32f1xx_hal_tim.o(i.TIM_TI1_ConfigInputStage))

[Stack]

- Max Depth = 8
- Call Chain = TIM_TI1_ConfigInputStage

[Called By]

- >> HAL_TIM_ConfigClockSource

TIM_TI2_ConfigInputStage (Thumb, 36 bytes, Stack size 8 bytes, stm32f1xx_hal_tim.o(i.TIM_TI2_ConfigInputStage))

[Stack]

- Max Depth = 8
- Call Chain = TIM_TI2_ConfigInputStage

[Called By]

- >> HAL_TIM_ConfigClockSource

UART_SetConfig (Thumb, 178 bytes, Stack size 16 bytes, stm32f1xx_hal_uart.o(i.UART_SetConfig))

[Stack]

- Max Depth = 16
- Call Chain = UART_SetConfig

[Calls]

- >> HAL_RCC_GetPCLK2Freq
- >> HAL_RCC_GetPCLK1Freq

[Called By]

- >> HAL_UART_Init

_dadd1 (Thumb, 0 bytes, Stack size unknown bytes, daddsub_clz.o(x$fpl$dadd), UNUSED)

[Called By]

- >> _dsub

_dsub1 (Thumb, 0 bytes, Stack size unknown bytes, daddsub_clz.o(x$fpl$dsub), UNUSED)

[Called By]

- >> _dadd

_fadd1 (Thumb, 0 bytes, Stack size unknown bytes, faddsub_clz.o(x$fpl$fadd), UNUSED)

[Called By]

- >> _fsub

_fsub1 (Thumb, 0 bytes, Stack size unknown bytes, faddsub_clz.o(x$fpl$fsub), UNUSED)

[Called By]

- >> _fadd

### Undefined Global Symbols

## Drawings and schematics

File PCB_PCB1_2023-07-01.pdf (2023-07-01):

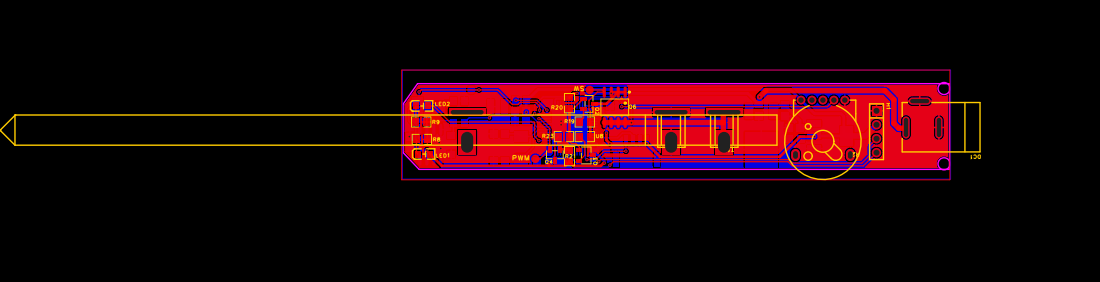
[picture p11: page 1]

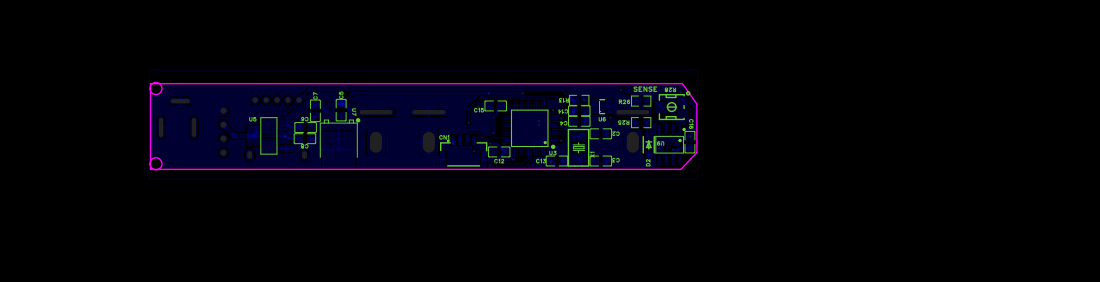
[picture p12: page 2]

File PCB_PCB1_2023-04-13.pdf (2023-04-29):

## THERMO

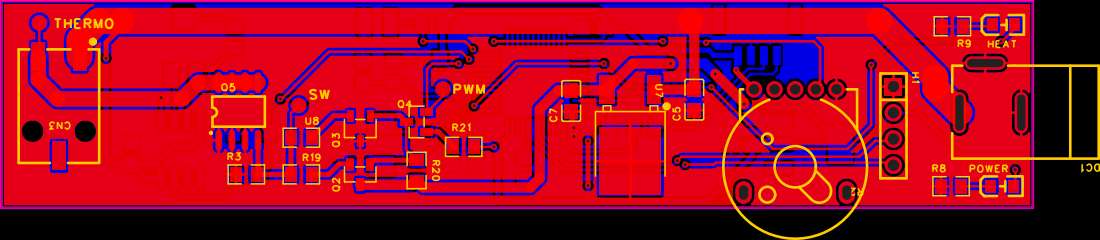
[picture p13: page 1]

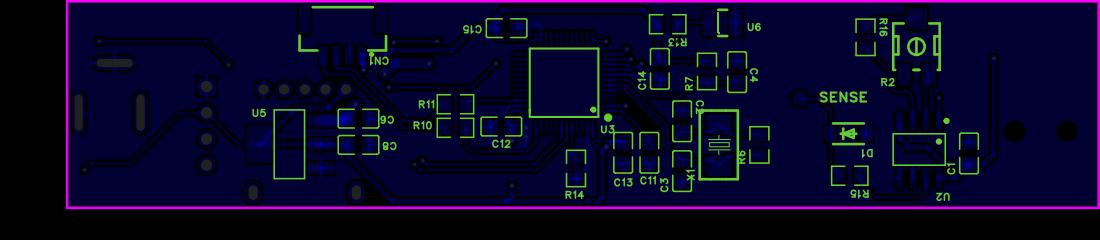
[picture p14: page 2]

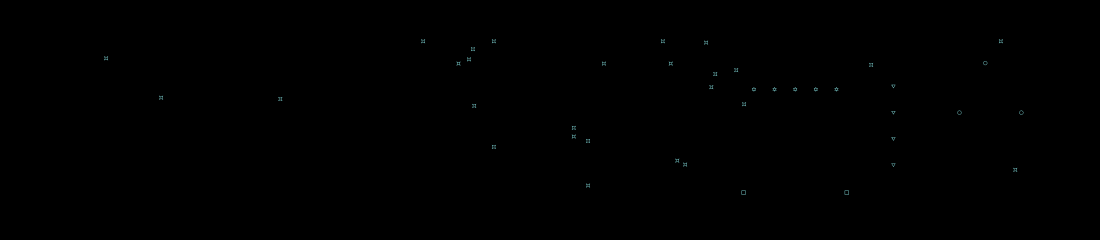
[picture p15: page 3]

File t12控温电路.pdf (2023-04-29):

## 烙铁头PWM输出 测温运放电路

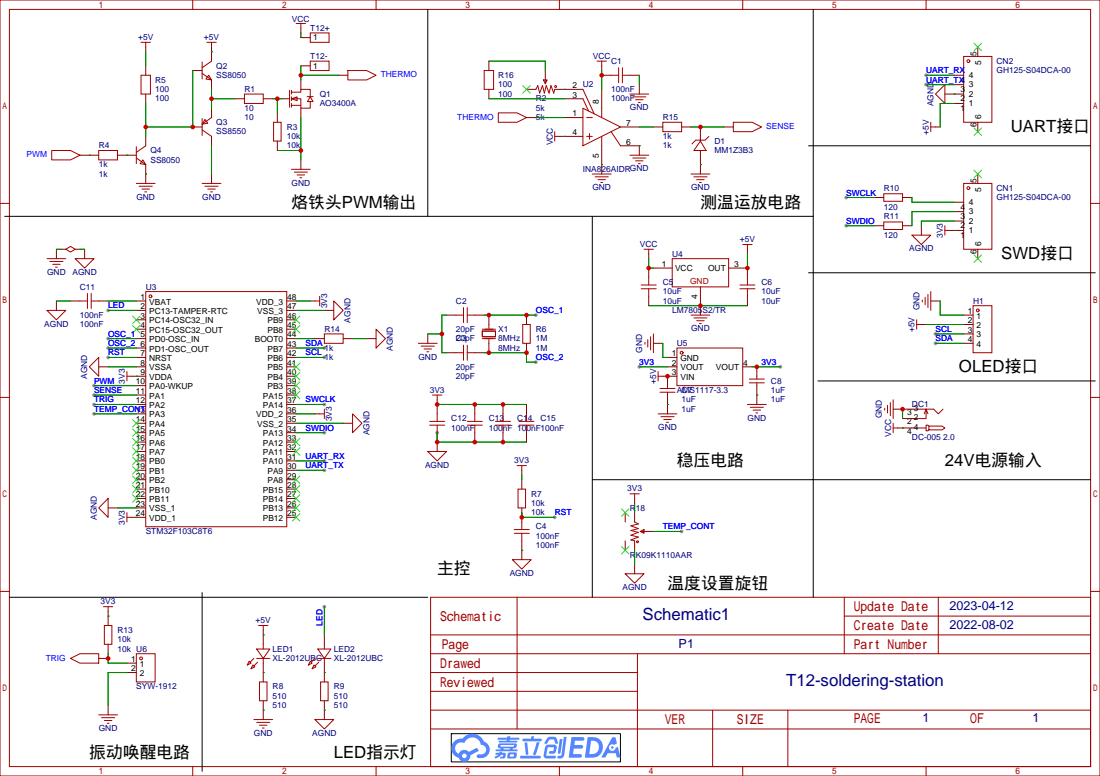
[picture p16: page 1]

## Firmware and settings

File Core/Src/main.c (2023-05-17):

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
/* Includes ------------------------------------------------------------------*/
#include "main.h"
#include "adc.h"
#include "i2c.h"
#include "iwdg.h"
#include "tim.h"
#include "usart.h"
#include "gpio.h"


void SystemClock_Config(void);
/* USER CODE BEGIN PFP */
uint8_t OLED_ShowStr(unsigned char x, unsigned char y, unsigned char ch[], unsigned char TextSize);
uint8_t OLED_Init(void);
uint8_t OLED_CLS(void);
uint8_t OLED_ShowCN(unsigned char x, unsigned char y, unsigned char N);

uint32_t cnt = 0;
int32_t pwm_max = 1000, temp_t = 50, pwm = 500;
int16_t temp_set = 300, temp_real, state = 1; //0:sleep; 1:awake
uint16_t measure_temp, measure_vibration, measure_temp_set;
float kp = 60, ki = 2, kd = 0;
float err, prev_err = 0, sum_err = 0;

int width = 16, offset = 14;
int teststate = 0;
#define oled_shownum(x,y,n) if(OLED_ShowCN(x,y,n)){HAL_I2C_MspDeInit(&hi2c1);HAL_I2C_MspInit(&hi2c1);MX_I2C1_Init();if(OLED_Init()){teststate++;}else {/*OLED_CLS();*/teststate = 0;}return;}
void oled_show(){
	//temp_real / temp_set
	int num = temp_real;
	if(state){
		oled_shownum(width * 6 + offset, 2, num / 100);
		oled_shownum(width * 5 + offset, 2, (num / 10) % 10);
		oled_shownum(width * 4 + offset, 2, num % 10);
	}else{
		oled_shownum(width * 7, 2, 11);
		oled_shownum(width * 6, 2, 11);
		oled_shownum(width * 5, 2, 11);
	}
	
	oled_shownum(54, 2, 10);
	
	num = temp_set;
	oled_shownum(32, 2, num / 100);
	oled_shownum(16, 2, (num / 10) % 10);
	//oled_shownum(0, 2, 0);
	oled_shownum(0, 2, num % 10);
	
}

/* USER CODE END PFP */

/**
  * @brief  The application entry point.
  * @retval int
  */
int main(void)
{
  /* MCU Configuration--------------------------------------------------------*/

  /* Reset of all peripherals, Initializes the Flash interface and the Systick. */
  HAL_Init();

  /* Configure the system clock */
  SystemClock_Config();

  /* Initialize all configured peripherals */
  MX_GPIO_Init();
  MX_ADC1_Init();
  MX_I2C1_Init();
  MX_USART1_UART_Init();
  MX_TIM2_Init();
  MX_IWDG_Init();
  /* USER CODE BEGIN 2 */
	OLED_Init();
	OLED_CLS();

	HAL_TIM_Base_Start_IT(&htim2);
	HAL_TIM_PWM_Start(&htim2, TIM_CHANNEL_1);
	HAL_TIM_OC_Start_IT(&htim2, TIM_CHANNEL_2);
	//HAL_ADC_Start_DMA(&hadc1, (uint32_t*)&adc_val, 3);
	
  /* USER CODE END 2 */

  /* Infinite loop */
  /* USER CODE BEGIN WHILE */

  while (1)
  {
    /* USER CODE END WHILE */

    /* USER CODE BEGIN 3 */
	    HAL_IWDG_Refresh(&hiwdg);
		oled_show();
	  
	  	HAL_GPIO_TogglePin(GPIOC,GPIO_PIN_13);//对GPIO口的电平进行反转（低-高，高—低）
		HAL_Delay(500);
	  
  }
  /* USER CODE END 3 */
}

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
/* USER CODE BEGIN 4 */


void ADC_Select_CH (uint32_t channel)
{
	ADC_ChannelConfTypeDef sConfig = {0};
	  /** Configure for the selected ADC regular channel its corresponding rank in the sequencer and its sample time.
	  */
	  sConfig.Channel = channel;
	  sConfig.Rank = 1;
	  sConfig.SamplingTime = ADC_SAMPLETIME_41CYCLES_5;
	  if (HAL_ADC_ConfigChannel(&hadc1, &sConfig) != HAL_OK)
	  {
	    Error_Handler();
	  }
}


void adc_scan(){
	ADC_Select_CH(ADC_CHANNEL_1);
	HAL_ADC_Start(&hadc1);
	HAL_ADC_PollForConversion(&hadc1, 1000);
	int temp_val = HAL_ADC_GetValue(&hadc1);
	if(temp_val < 3800){
		measure_temp = measure_temp * 0.95 + HAL_ADC_GetValue(&hadc1) * 0.05;
	}
	HAL_ADC_Stop(&hadc1);
	ADC_Select_CH(ADC_CHANNEL_2);
	HAL_ADC_Start(&hadc1);
	HAL_ADC_PollForConversion(&hadc1, 1000);
	measure_vibration = HAL_ADC_GetValue(&hadc1);
	HAL_ADC_Stop(&hadc1);
	ADC_Select_CH(ADC_CHANNEL_3);
	HAL_ADC_Start(&hadc1);
	HAL_ADC_PollForConversion(&hadc1, 1000);
	measure_temp_set = measure_temp_set * 0.95 + HAL_ADC_GetValue(&hadc1) * 0.05;
	HAL_ADC_Stop(&hadc1);
}
void HAL_TIM_OC_DelayElapsedCallback(TIM_HandleTypeDef *htim){
	HAL_IWDG_Refresh(&hiwdg);
	if(htim == &htim2){
		if(htim->Channel == HAL_TIM_ACTIVE_CHANNEL_2){
			cnt++;
			adc_scan();
			//calculate temperature
			temp_set = (float)measure_temp_set / 4096 * 200 + 200;
			temp_real = measure_temp * 0.1238 + 17.2814;
			//pid=>pwm
			err = temp_set - temp_real;
			if(err < 10) sum_err += err;
			if(sum_err > 100) sum_err = 100;
			else if(sum_err < -100) sum_err = -100;
			if(err <= 0) pwm = 0;
			else pwm = kp * err + kd * (err - prev_err) + ki * sum_err;
			if(pwm > 1000) pwm = 1000;
			if(pwm < 0) pwm = 0;
			if(state == 0) pwm = 0;
			prev_err = err;
			//pwm = (float)measure_temp_set / 4096 * 1800;
			TIM2->CCR1 = pwm;
			
			//sense vibration
			if(measure_vibration > 1000){ //threshold
				cnt = 0;
				state = 1;
			}else if(cnt > 20000){ //1 min no movement
				state = 0;
			}

		}
	}
}


/* USER CODE END 4 */
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


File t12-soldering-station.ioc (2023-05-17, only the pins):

Mcu.UserName=STM32F103C8Tx
PA0-WKUP.Signal=S_TIM2_CH1_ETR
PA1.Signal=ADCx_IN1
PA10.Signal=USART1_RX
PA13.Signal=SYS_JTMS-SWDIO
PA14.Signal=SYS_JTCK-SWCLK
PA9.Signal=USART1_TX
PB6.Signal=I2C1_SCL
PB7.Signal=I2C1_SDA
PC13-TAMPER-RTC.Signal=GPIO_Output
PD0-OSC_IN.Signal=RCC_OSC_IN
PD1-OSC_OUT.Signal=RCC_OSC_OUT

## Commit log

2023-04-29 pid控温
    剩下oled显示与振动唤醒
    控温曲线待测
    [BOM_Board1_PCB1_2023-04-13.xlsx]
2023-04-30 振动唤醒
2023-05-07 new pcb
    [3DShell_3DShell_PCB1_B.stl, 3DShell_3DShell_PCB1_T.stl]
2023-05-17 final version
    [3DShell_3DShell_PCB1_B.stl, 3DShell_3DShell_PCB1_T.stl]

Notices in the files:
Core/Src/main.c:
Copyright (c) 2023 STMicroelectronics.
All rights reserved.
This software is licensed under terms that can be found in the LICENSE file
